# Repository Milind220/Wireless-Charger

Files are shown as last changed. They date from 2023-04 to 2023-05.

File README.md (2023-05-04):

# The *Smart Charge* System

All the code and design files for the wireless charging system that I made for my final year project! This is the capstone project for my undergraduate degree in Energy Science and Engineering!

*Summary*:

A custom built, high power, smart wireless charging system for robotics. The charger transmitter can be controlled from a sleek online dashboard, and the charging mode, output voltage, current, and power can also be monitored. The charger automatically detects the presence of a robot on the charging pad, and switches from STANDBY to ACTIVE charging mode. It also features a closed-loop feedback system to reach the target charging voltage for the robot.



## Contents
* [Inverter-Controller](#inverter-controller) - The code for controlling the inverter.
* [WebLink-Primary](#weblink-primary) - The code for the primary (transmitter) side weblink.
* [WebLink-Secondary](#weblink-secondary) - The code for the secondary (receiver) side weblink. 
* [Secondary-sensor-reader](#secondary-sensor-reader) - The code for the secondary side sensor reader device.
* [Smartcharge-dashboard](#smartcharge-dashboard) - The online control and monitoring dashboard.
* [Hardware](#hardware) - Electronics schematics, gerber files, and STLs.
* [Simulations and Modelling](#simulations-and-modelling) - EasyEDA circuit simulation, and system modelling Excel sheet.
* [Report and Presentation](#report-and-presentation) - my FYP final report and presentation.

## Inverter Controller

The [inverter controller](https://github.com/Milind220/Wireless-Charger/tree/main/Inverter-Controller) is a Teensy 4.1 microcontroller board. It uses 4 precisely timed PWM signals to control an H-Bridge inverter with phase-shift control, which then generates a modified square wave signal that is used to energise the primary (transmitter) coil. It also uses a single digital pin to control the enable/disable function of the MOSFET driver ICs. It also gets signals for the mode to control the inverter from an ESP32 that communicates with it using i2c. 

The Teensy 4.1 was chosen for this task for the following reasons:
* Arduino compatibility, which makes it ideal for rapid development.
* High speed microcontroller. The Teensy's core is a NXP i.MX RT1062 that runs at 600 Mhz.
* Capable of producing very high speed, high resolution, precisely timed and coordinated PWM signals.

The 4 PWM signals are produced as two pairs of complementary signals, with a fixed duty cycle of 50% and frequency of 100 kHz. The two pairs of signals have a variable phase shift (0-90 degrees), and the degree of phase shift controls the output waveform from the inverter. The RT1062's eFlexPWM module also inserts deadtime, so that shoot through doesn't occur between same-side MOSFETs.

A more detailed explaination of the code is given in the Inverter Controller directory. 

## WebLink Primary

The [Primary Side WebLink](https://github.com/Milind220/Wireless-Charger/tree/main/WebLink-Primary) is an ESP32 development board that communicates with the Teensy 4.1 inverter controller via i2c. It obtains the secondary side voltage and current information from the connected Firebase realtime database. This is then used to derive the mode command that it sends to the Teensy. It also sends the Teensy the secondary voltage level, which is used to implement the closed loop control algorithm.

ESP32's are low cost, easy to use, and incredibly powerful (probably overkill for this task). They are also Arduino Compatible, which once again helps with rapid development.

## WebLink Secondary

The [Secondary Side WebLink](https://github.com/Milind220/Wireless-Charger/tree/main/WebLink-Secondary) is an ESP32 development board that sends receiver voltage, current levels to the Firebase realtime database. However, this board does not connect directly to the voltage, current sensors. The sensors used operate at a voltage of 5V, and have analog outputs, which makes it likely that they would damage the ESP32s GPIOs if connected directly. Instead, the ESP32 interfaces with an Arduino Nano via i2c, which is instead used to reads the sensors.

## Secondary Sensor Reader

The [secondary side sensor reader](https://github.com/Milind220/Wireless-Charger/tree/main/secondary-sensor-reader) is an Arduino Nano that reads the analog inputs from the voltage and current sensors. It converts the ADC readings into the actual voltage and current values and then sends those to the WebLink Secondary device via i2c (through a logic level shifter).

## SmartCharge Dashboard

This is the [control and monitoring dashboard](https://github.com/Milind220/Wireless-Charger/tree/main/smartcharge_dashboard) for the SmartCharge System. It is used to view the charging mode, as well as receiver voltage, current, and power in real-time. It can also send on/off commands to the charging station.

## Hardware

This folder contains the electrical schematics and gerber files for the project. This includes the schematics for the inverter and secondary-side control board.

## Simulations and Modelling

This [folder]() contains:
* The EasyEDA simulation done to analyse the resonant frequency of the system, and to confirm the values of the LCC network's capacitances and inductances.
* The MATLAB code used to calculate the LCC compensation network values.
* The Excel file used to model the entire system.

## Report and Presentation

Files in this folder:
1. [FYP final report](https://github.com/Milind220/Wireless-Charger/blob/main/Report%20and%20Presentation/FYP%20Final%20PPT.pptx) 
2. [FYP final presentation](https://github.com/Milind220/Wireless-Charger/blob/main/Report%20and%20Presentation/final_report_55805388_milind_sharma.pdf)

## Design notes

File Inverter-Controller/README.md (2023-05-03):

# Inverter Controller

This is a Teensy 4.1 that is used to control an H Bridge inverter using the PWM outputs. It also communicates with the WebLink Primary board via i2c, and adjusts it's mode of operation according to commands from there.

## General Code explaination

1. Configured as i2c master device.
2. Requests a tranmission from the ESP32 Primary Weblink (slave device)
3. Reads the i2c bytes sent from the slave. 5 bytes are sent:
    1. secondary side voltage (2 bytes)
    2. secondary side current (2 bytes)
    3. mode of operation (1 byte)
4. Switches to the appropriate mode of operation. Different mode functions are defined in the code, and are called from the loop function.
5. The eFlexPWM library is used to control the PWM outputs, and generate two pairs of complementary PWM with deadtime and variable phase shift, at a 100 kHz frequency. These are used to drive the H Bridge inverter.

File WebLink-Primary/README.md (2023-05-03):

# WebLink Primary

This is the Web-link board for the primary (transmitter) side. It receives the secondary side voltage/current from the Firebase realtime database, and sends it via i2c to the inverter controller (Teensy 4.1). The board itself is an ESP32 dev module.

> This is created as an Arduino project, as for some (currently unknown) reason the code refused to compile with Platform.io, but readily compiled with Arduino.

## Brief explaination of code
1. Firebase ESP Client library (v4.3.10) by mobizt is used to get data from Firebase realtime database
2. Wire library is used for i2c communication
3. ESP32 is set-up as i2c slave device
4. It waits for a request from the master device (teensy 4.0 inverter controller), and then sends 5 bytes of data:
    1. 2 bytes for voltage
    2. 2 bytes for current
    3. 1 byte for mode
5. The mode byte is used to indicate the mode of operation of the inverter controller. The modes are:
    1. 0: OFF
    2. 1: STANDBY
    3. 2: ACTIVE
    4. 3: OFFLINE

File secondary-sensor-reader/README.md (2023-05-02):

# Secondary Side Sensor Reader Device

This is the code responsible for reading the values of the voltage and current sensors connected to the receiver (Rx) coil. It is written to run on an Arduino Nnano (AtMega328P).

This is done because the voltage/current sensors used in this project run on 5V while the WebLink (ESP32 board) runs on 3.3V. Thus the sensors cannot be directly connected to the ESP32 without damaging the microcontroller hardware. Since the signal from the sensors is analog, it cannot be routed through a logic level-shifter either. Instead the Arduino Nano reads from the sensors, and sends the readings to the ESP32 using i2c (through a logic level shifter).

## Setup
It carries out the following tasks:
* Reads analog values from voltage and current sensor using ADC.
* Converts ADC values to actual voltage/current readings.
* Sends the values over i2c (through a logic level shifter) to the secondary side WebLink (ESP32 board).

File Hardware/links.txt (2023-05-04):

Inverter: https://oshwlab.com/milind220/new-inverter 
Secondary Side Weblink and sensor reader: https://oshwlab.com/milind220/weblink-secondary

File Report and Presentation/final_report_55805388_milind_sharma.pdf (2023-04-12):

## CITY UNIVERSITY OF HONG KONG

## Development of a Smart Wireless Charging System for Robotics

Submitted to
School of Energy and Environment
in Partial Fulfilment of the Requirements for the Degree of Bachelor of Engineering in Energy Science and Engineering

by

SHARMA Milind

2023.4

s

## Outline

## Acknowledgements:

I am deeply grateful for the support and assistance I have received in the completion of my

undergraduate final project. This project was made possible through a number of grants and

projects, including the grant (Project No. 52077186) from the Natural Science Foundation of

China (NSFC), China; the grant (Project No. JCYJ20210324134005015) from the Science

Technology and Innovation Committee of Shenzhen Municipality, Shenzhen, China; the

grants (Project No.: ITP/027/19AP and ITS-045-21) from Innovation and Technology

Commission (ITC) of Hong Kong SAR; the grant (Project No.: ECF Project 56/2021) from

Energy and Conservation Fund and Woo Wheelock Green Fund of Hong Kong SAR; the

Teaching Development Grant (Project No. TDG 6000784) from City University of Hong

Kong, Hong Kong SAR; the Applied Research Project (9667251) from City University of

Hong Kong, Hong Kong SAR; the grant of Collaborative Research Fund (Project No. C1052-

21GF) from the Research Grants Council of Hong Kong SAR; and the RGC Research Fellow

Scheme (RGC Ref. No. RFS2223-1S05) from Research Grants Council, Hong Kong SAR.

I would also like to express my gratitude to my FYP supervisor, Dr. Chunhua Liu, for his

invaluable guidance, suggestions, and unwavering support throughout the entire duration of

this project. His expertise and advice have greatly contributed to my academic growth and the

development of my research and writing skills. Additionally, I would like to extend my

sincere appreciation to my mentor, PhD candidate Yuxin Liu, who has been instrumental in

shaping my research direction, expanding my professional knowledge, and honing my

practical skills.

Wireless power transfer was initially an unfamiliar area for me, and I encountered numerous

unforeseen challenges while commissioning my prototype. With the continuous support and

encouragement from my mentor, supervisor, and the grants and projects mentioned above, I

was able to overcome these obstacles and successfully complete my project. Their combined

expertise and backing have been indispensable in my journey, and I am extremely thankful

for their mentorship and assistance.

## Abstract:

This paper presents the development of a smart wireless charging system for robotics,

focusing on the integration of IoT technology and an LCC-S compensation-based one-to-one

system operating at 100 kHz. The primary goal of this research is to provide a smart, remote-

controlled, and monitored wireless power transfer (WPT) system that is tailored to charging

robotics systems. By integrating IoT technology, the system allows users to remotely control

and monitor the WPT system via a dashboard, which displays crucial information such as

charging voltage, current, output power, efficiency, and the presence of a secondary coil.

Furthermore, the dashboard facilitates the remote control of the charger's on/off state. In

addition to remote control and monitoring, the IoT system enables feedback control for the

primary side, switching between active and standby modes based on the detection of the

secondary coil. In active mode, the inverter provides constant output to the transmitter coil,

while in standby mode, the output pulses every 500 ms to conserve energy. The IoT system

also dynamically adjusts the phase-shift control in the inverter to regulate output power on

the secondary side, meeting target power requirements. The proposed WPT system

demonstrates a maximum efficiency of 64.28% with a power transfer of 75 W across a 4 cm

air gap, with potential for higher power transfer untested due to equipment limitations. While

designed for the Hunter SE rover, the system can be easily adapted for use with other robotic

platforms. This smart wireless charging system offers significant improvements over existing

solutions, including real-time remote control and monitoring, seamless IoT integration,

adaptability to various robot models, and enhanced charging efficiency.

## Chapter 1: Introduction:

### 1.1. Research Background:

The advent of the electrical age has led to extensive discussions and research on charging and

power transformation technologies. Traditional charging methods that rely on wired

connections, provide considerable power capacity and efficiency but limit mobility, reduce

durability and aesthetics, and impede waterproofing capabilities. Nikola Tesla revolutionized

the concept of wireless power transfer (WPT) with the invention of the Tesla Coil, a high-

frequency, air-core, resonant transformer capable of generating very high voltages and

creating electrical discharges. The Tesla Coil was designed to transmit electrical energy

wirelessly through the Earth's atmosphere, and established the foundation for further research

into WPT technologies [1]. Near-field non-radiative transfer emerged from this area, which

enabled wireless energy transfer across short distances but with relatively low power outputs.

A pioneering study conducted by a team at MIT in 2007, as illustrated in Figure 2, introduced

magnetic resonance power transfer (MRPT), allowing electricity to be transmitted through an

air gap over a few metres with high power capacity [2]–[4]. Innovations like this provided

WPT with the credibility and practicality needed to gain broader adoption and commercial

success, as evidenced by products from WiTricity Corporation [5]. Today, advances in WPT

technology, combined with 'smart' technology, have led to the integration of smart wireless

chargers in most mainstream devices, such as mobile phones, laptops, and headphones. These

chargers typically feature overcharge protection, automatic shut-off when the device is fully

charged, LED indicators for charging status, adjustable charging speeds based on battery

health, and charge optimization, ultimately aiming to deliver efficient charging alongside an

excellent user experience.

(a) (b)
Figure 1: WPT 60W light bulb over 2m distance. (a) Without barrier. (b) With barrier. [2]

The field of robotics, however, has been slow to adopt and implement this technology.

Previous studies on the integration of smart WPT systems with robotics have focused mostly

on coil topologies [6], multiple device charging [7], [8], efficient charging algorithms [9], and

better compensation networks [10]. While these are important areas of research to continue

the improvement of the underlying WPT technology, these papers do not provide a

framework to create charging systems that are easy and modern to control and monitor – both

of which are core tenets of smart technology. Therefore, there is a need for a solution that

integrates true smart features with effective wireless charging abilities and a simple system

architecture.

### 1.2. Research Objectives:

The main objective of this project is to build a wireless charging system for a specific robot

platform, with a novel solution to provide misalignment tolerance, as well as a smart

dashboard and user control interface.

The tasks performed in order to accomplish this goal are listed below:

1. Literature review of the background and history of wireless power transfer, with a

focus on the employment of smart technology in this field.

2. Overview of the design of the WPT system built.
3. Summary of different coil topologies, as well as a detailed analysis on the single

primary, single secondary coil system selected for this project.

4. Design and fabrication of a custom high power inverter circuit board.
5. Analysis of compensation network options, as well as justification and explanation of

the LCC network selected for this project.

6. Integration of a smart online dashboard for control and monitoring of charging system

using Internet of Things (IoT) technology.

## Chapter 2: Literature Review:

Large amounts of research have been done on the field of wireless power transfer and

wireless charging. This section contains a thematically organised summary of the knowledge

required to build an intelligent wireless charging system for a robotics platform.

### 2.1. Development of Wireless Power Transfer:

Conventional charging systems involve connecting a charging plug to a device for power

transfer. This method has several disadvantages: the wire and plug may deteriorate due to

constant plugging and unplugging; the device is confined to a specific location; and sparks

may be produced. Over the years, a wire-free charging technique known as wireless power

transfer has emerged, eliminating the constraints associated with wired charging. This

technology has become increasingly popular and now has numerous applications, including

smartphone and headphone charging [11], implantable medical devices [12], electric vehicle

wireless charging [13], and drone and logistics robot charging [14], [15].

In 1888, Heinrich Hertz discovered the existence of electromagnetic waves and conducted

research into their behaviour. His work helped future scientists understand the concepts of

electromagnetic waves, laying the foundation for future research into this field [16]. Nikola

Tesla, in 1891, made many important contributions to the field of WPT, such as the

aforementioned Tesla coil [1]. However, following this period, due to constraints in

electronic components and related technology, there was limited product development and

research during the early 20th century. Over the following decades, the popularity of

radiation-based WPT gradually increased and in 1966, American engineer William C. Brown

conducted a point-to-point power transfer experiment using radiation, achieving an efficiency

of 26% [17]. Subsequently, in 1968, scientist Peter Glaser theorised about a large solar

powered satellite system capable of converting solar radiation into electromagnetic beams

and transmitting solar energy to Earth [18].These developments eventually led to the

popularisation of non-radiative near-field WPT, which can be further divided into inductive

coupling and magnetic resonant coupling WPT, also known as resonant inductive coupling.

Simple inductive coupling relies on the concept of induced EMF to transfer energy across an

air gap. Magnetic resonant coupling improves on this by additionally also setting both coils to

the same resonant frequency, greatly increasing efficiency and range. The operating

frequencies and transmission ranges of different WPT systems can be seen in figure 2.

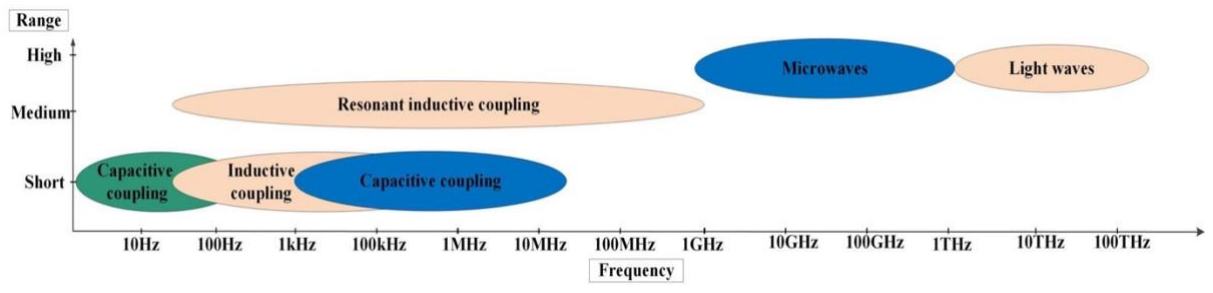
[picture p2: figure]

Figure 2: Review of different technologies in WPT [13].

### 2.2. Fundamental Concepts of Wireless Power Transfer:

Wireless power transfer (WPT) is broadly governed by two fundamental laws of physics,

Ampere's Circuital Law and Faraday's Law of Induction. Ampere's Law states that when a

current flows through a conductor, a magnetic field is generated whose strength is

proportional to the magnitude of the current and the permeability of free space [19]. This

relationship can be mathematically expressed as follows:
∮ B⃗ ∙ dl ⃗ = µ0NI | (1)

Faraday's Law of Induction, on the other hand, states that a time-varying magnetic flux

intersecting a surface formed by a conducting coil induces a time-varying electromotive force

in the circuit, whose magnitude is proportional to the rate of change of the flux and the

number of turns in the coil [20]. This induced emf creates induced current. Mathematically,

this is expressed as follows:

induced emf = −N ∙

dφ
dt | (2)

Together, these laws provide a fundamental model for the interaction between electric

currents, voltages, and magnetic flux in WPT systems. In such systems, two coils, primary

and secondary, are separated by an air gap, and high-frequency alternating current is passed

through the primary coil. This creates a time-varying magnetic field around it, as described

by Ampere's Law. Part of this magnetic flux intersects with the surface formed by the

secondary coil. The amount of flux that interests with the secondary coil is directly related to

the coefficient of coupling, k, with higher coupling implying higher efficiency. In accordance

with Faraday's Law, the magnetic flux induces an emf in the secondary coil, which produces

a current.

However, such systems are inductive but non-resonant and suffer from significant energy

losses through leakage inductance and copper losses in the coils. Coupling efficiency

decreases as the distance between coils increases, making them suitable mostly for close-

range power transfer. For mid-range WPT, an inverter with a large V-A rating would be

required to transmit sufficient power [13]. To fix the flaws of simple inductive coupling,

magnetic resonant coupling is introduced in most practical modern systems. It is well known

that two resonant objects are highly efficient at exchanging energy, while nearby non-

resonant objects are largely ignored. Therefore, the suitability of magnetic resonance for

WPT is even higher since most everyday objects do not interact with magnetic fields [13].

Figure 3: Fundamental concepts of WPT [13].

### 2.3. Integration of Smart Technology with Wireless Power Transfer:

Smart technology, also referred to as the Internet of Things (IoT), consists of a wide array of

interconnected devices leverage advanced sensors, data processing, and communication

capabilities to form a system that can perform tasks intelligently and autonomously [21]. This

technology can be used to develop solutions that enhance efficiency and user experience by

providing a constant stream of information about all devices of any kind in the network [22].

The feature that is key to the effectiveness of smart technology is the ability to process and

analyse real-time data. If applied to a WPT system, this technology could be used to

communicate between the transmitter and receiver coils, provide real-time charging related

information to the user, and even detect issues such as coil misalignment in the charging

process.

In [23], a smart, autonomous WPT system is proposed to enable easy charging for electric

wheelchairs. The paper presents a supervisor system which continuously coordinates and

analyses data between the charging dock and the wheelchair receiver coil, thus maintaining safe operation of the charger at a high level, without requiring human interference. A similar

approach to create a smart wireless charging system for electric wheelchairs is described in

[24], using technology closer to modern IoT to create a hands-free system that communicates

with the central computer of the system via Robot Operating System (ROS) and provides an

Android app that displays charging information and allows the user to control the power

transmitter.

There have also been other approaches to make wireless charging systems more modern,

capable, and intelligent, which can be somewhat classified as smart WPT. One main

approach to improving wireless charger capabilities is through the exploration of multiple-

transmitter/receiver coil configurations. Multiple transmitter coil systems have been used for

the purpose of Dynamic Wireless Power Transfer (DWPT). This variation of WPT

technology aims to enable charging of robots while they operate and are in motion, which is

an improvement over static charging, and could be considered smart charging. One analysis

designed a DWPT system for logistics robots, such as the ones used in warehouses [15]. This

system utilises a many-to-one coil arrangement and an LCC-S compensation network to

enable dynamic charging, and was able to achieve a maximum efficiency of 74.51% at 1.5

kW rated power with the receiver in motion. Other studies have looked into multicoil

transmitter arrays as a method of achieving more intelligent charging. In such systems,

misalignment tolerance is addressed by tracking the position of the receiver coil through

detecting changes in transmitter coil characteristics, and only using aligned coils to transmit

power to the receiver [6].

‘Smart’ multiple receiver coil systems (one-to-many) have also been explored. One such

system, designed with a single transmitter and 3 miniature receiver coils, developed a method

based on separating the resonant frequencies of the receivers to select and deliver power to

only one receiver coil at a time, eliminating cross coupling losses [25]. Using this approach, a

maximum efficiency of 29% was observed despite the small coupling coefficient of only

0.01. These advanced coil arrangements each have specialised advantages. One-to-many

chargers allow for charging of multiple devices; many-to-one arrangements provide much

greater misalignment tolerance; many-to-many arrangements incorporate advantages of both.

While these different coil arrangements are often necessary to solve certain problems, they do

not make use of the advancements of the IoT sector. Thus, they forego the benefits of online

monitoring, remote control, and more advanced communication channels.

Another area of advancement for wireless charging has been in the development of charging

standards, such as the “Qi Standard” developed by the Wireless Power Consortium and

“Power Matters Alliance Standard” (PMA) developed by the Airfuel Alliance. Among other

things, these standards specify the design of a communication standard between the

transmitter and receiver [11]. This is related to smart technology as it provides the simplicity

to use any standard-compliant transmitter-receiver pair and have the wireless charging work

correctly. It is important to note that transmitter-receiver communication occurs over the

same coils used for charging, adding a degree of complexity to the charger design [26]. The

PMA standard does incorporate smart features, emphasizing cloud-based device

management, offering smart features such as usage monitoring, remote diagnostics, and over-

the-air firmware updates [11].

(a) (b)
Figure 4: Smart interface for WPT system [24]. (a) Relationship between system central computer and android app. (b) Android mobile application used for monitoring and control.

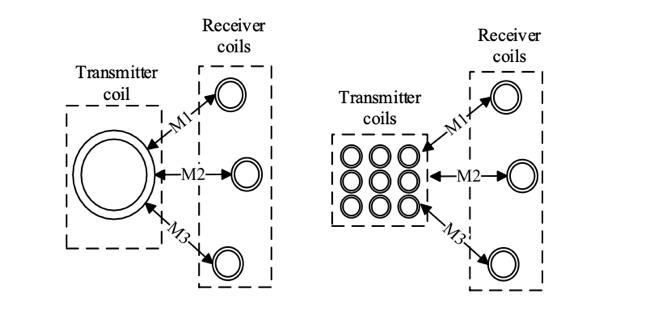
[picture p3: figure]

(a) (b)
Figure 5: Multiple receiver coil topologies; (a) Single In Multiple Out (SIMO) and (b) Multiple In Multiple Out (MIMO).

### 2.4. Motivation and Description of the Project:

The motivation for pursuing this project comes from my experience in robotics and software

development. During a summer internship at a robotics company, I noticed that in most cases,

the robots had to be manually charged using a wired connection – a repetitive task that should

have been rendered outdated with the popularisation of wireless charging and smart technology. Further research revealed that most robotics systems that are WPT enabled are

either very high power applications (kW), very low power application of a few Watts or less

[27]. As such there is a dearth of ready-made medium power WPT capabilities for robotics

platforms.

The purpose of this project is to introduce a truly smart wireless power transfer system that is

custom built for a specific robotics system, to provide exact charging voltage and current that

it requires. Affordable and modern IoT technology connected to the WPT system will enable

the creation of a multi-platform, online charger control and monitoring dashboard.

Information gathered by the IoT devices on the receiver and transmitter sides will also be

analysed in order to implement a feedback and control system. Using this, the transmitter coil

will be switched to standby mode if receiver coil is not detected to save energy. Also the

inverter output power will be varied using phase-shift control, based on the feedback obtained

from the secondary coil. The system will use an internet enabled microcontroller board on

both the transmitter and receiver sides in conjunction with other system elements to facilitate

the IoT features. The proposed system will feature a one-to-one (O2O) coil arrangement

where both coils are identical in size and shape to simplify the coil architecture. An

appropriate LCC compensation network will utilised in order to reduce sensitivity to

variations in coupling coefficient and load impedance, which leads to higher stability and

efficiency. The online dashboard will be used to control the charger system and view

charging information in real-time remotely. This, along with a modern and appealing design

for 3D printed enclosures will result in a WPT system that is both a capable charger and also

user friendly and visually appealing.

## Chapter 3: Methodology:

The section on methodology consists of two sections. The first section, theoretical

framework, contains all the theoretical concepts and design principles involved in this

project. The second section, experimental methodology, covers the steps taken for the

practical design of the system, how certain parameters were experimentally determined, and

how certain components were selected. This includes measurements, simulations, and other

practical design decisions.

### 3.1. Theoretical Framework:

### 3.1.1. General System Architecture:

Figure 7 displays the architecture of the smart WPT system proposed in this paper. In this

section, a general system overview is provided with a focus on the WPT parts, while section

3.1.6 covers the IoT network structure in detail.

On the primary side, stable DC power is supplied to the inverter, which then modulates it into

a modified square wave. The transmitter (Tx) coil is energised by the modified square wave

and compensated by the LCC network so it resonates at the system operational frequency. In

this state, the Tx coil transfers energy to the receiver (Rx) coil across an air gap. On the

secondary side, the induced voltage produces alternating current, which is then compensated

and rectified into direct current. The direct is then used to charge the load. The proposed coil

design consists of inverter, LCC-S compensation network, and one-to-one transmitter and

receiver coil system. The primary and secondary side are both additionally monitored by

internet enabled microcontrollers, which process and send charging information to an online

database. This information is then available for viewing on the online dashboard, and also

used to implement feedback control for the primary side without manual operation.

### 3.1.2. Coil Topology:

In this paper, a one-to-one coil (O2O) topology – as shown in figure 8 [28] is proposed,

utilizing identical circular coils for both the primary (transmitter) and secondary (receiver)

sides. This configuration provides a simple approach to wirelessly transfer power between the

charging station and the robot, which reduces system complexity.

A O2O topology is a suitable choice for applications where a single transmitter coil (TX) is

supposed to charge a single receiver coil (RX) on the robot. This configuration offers the

advantage of straightforward design, as it does not require the complex control mechanisms

and communication protocols needed for multi-coil arrangements. O2O coil topologies also

simplify the problem of stable and efficient power transfer in the event of misalignments

between the charging station and the robot, as fewer coil positions have to be taken into

account. Lastly, the simple design of the O2O topology allows this paper to focus on the

implementation of a robust smart IoT network.

Figure 7: One-to-one coil topology [28].

Figure 6: System architecture of proposed smart WPT system

### 3.1.3. Coil Modelling:

Prior to design of the physical coils, coil modelling was performed to obtain estimations of

their properties in advance. As described in detail in section 3.2.2., circular coils were chosen

for this system. These parameters were modelled for circular coils: self-inductance; inner

diameter; coil area. All modelling in this section is based on the framework laid out in [29] as

applied in [30], and can calculate inductance with ~1% maximum error:
Din(mm) = Dout − (2N ∙ (dwire + s)) | (3)

Where Din is inner diameter of coil, Dout is outer diameter of coil, N is number of turns,

dwire is wire diameter, s is turn spacing (all distances are in mm). Wire length can be

calculated from this as well, which can help derive coil resistance.

wire lengtℎ (m) =

Nπ
1000 ∙

(Din + Dout)
2

(4)

Inductance can also be estimated in this manner. R and W are intermediate parameters used

for this calculation, and their derivations are in the Appendix.

inductance (µH) =

R

2
- N

2
8R + 11W

(5)

### 3.1.4. LCC-S Compensation Network:

For the system proposed in this paper, a LCC-S (inductor-capacitor-capacitor-series)

compensation network is utilised. The decision to utilise an LCC network is based on the

principle that it can facilitate constant output voltage and constant primary coil current. The

working principles behind this compensation technique are discussed in this section.

The requirement for a compensation network in WPT systems stems from desire to

improving certain characteristics in the system. For the system proposed in this paper, those

characteristics include: constant current/constant voltage output that is not sensitive to load

resistance; Low input reactive power, Low sensitivity to variation in the coupling coefficient,

which can broaden the range of possible applications [31]. Of the many initial compensation

networks that emerged as options, series-series (SS) compensation was the most effective to

achieve these goals [32]. However, due to low performance in the event of coil misalignment,

higher order compensation such as LCC networks have been explored [33], [34]. Figure 8 shows the practical configuration of the LCC-S compensation network, where LP1

, CP1 and

CP2 are the inductance, parallel capacitance, and series capacitance in the compensation

network, and LP is the inductance of the primary coil. As mentioned earlier, a feature of LCC

compensation networks is that when operating at the resonant frequency, transmitter coil

current is independent of the coupling coefficient and secondary coil load, facilitating

constant current output for the transmitter. In order for this to happen, the following

relationships must be satisfied [33]:

jωLP1 = −

1
jωCP1

→ LP1

- CP1 =

1
ω²

(6)

jωLP1 = jωLP +

1
jωCP2

→ (LP1
- LP

) ∙ CP2 =

1
ω²

(7)

To further analyse the LCC compensation, Figure 9 shows the T-equivalent circuit diagram

of the resulting system when the transmitter and receiver coils are coupled together, which is

used for showing the constant primary current. The impedance reflected from the secondary

side is represented here as Zre1
. Using this, the total impedance on the primary side can be

calculated:

Z0 = jωLP1 +

1
jωCP1

|| (

1
jωCP2
+ jωLP + Zre1) | (8)

Simplifying (8) using equation (6) and (7), we derive a new equation for Z0 :

Z0 =

ω²
- LP1

2

Zre1

(9)

This can now be used to model the current in the transmitter coil, assuming that the voltage

provided in the transmitter coil by the inverter is Uin1
. Equation (5) can be then be derived:

IP1 =

Uin1

∙

1
jωCP1

|| (

1
jωCP2

+ jωLP + Zre1)

Z0

- (

1
jωCP2

+ jωLP + Zre1)

(10)

Which can then be simplified further to:

IP1 =

Uin1
jωLP1

(11)

Equation (11) shows that the value of IP1
, the transmitter coil current, is not dependant on the

impedance reflected from the secondary side. This ensures that any variation in mutual

inductance that occurs when the robot is moving on the charging station does not affect the

current in the primary coil.

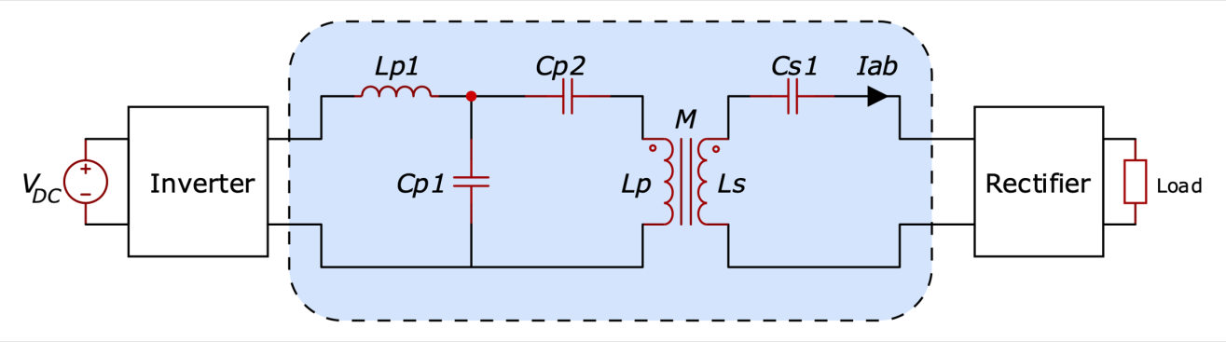
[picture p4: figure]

Figure 8: Practical configuration of LCC-S Compensation Network.

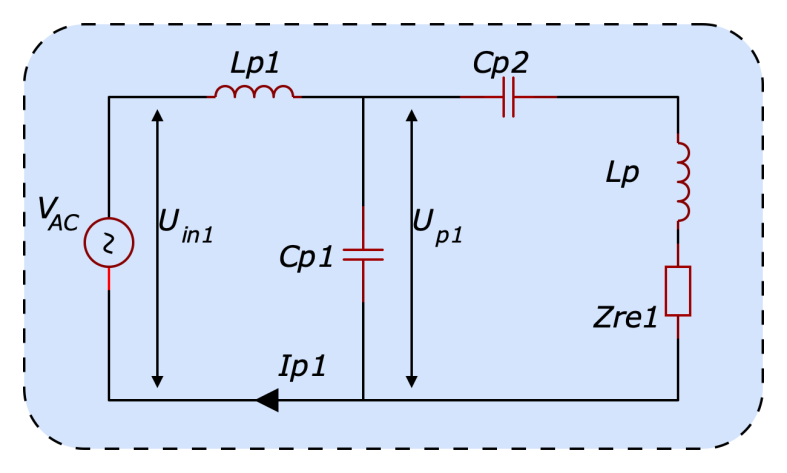
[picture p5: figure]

Figure 9: T-Equivalent circuit of primary side to show constant Tx coil current.

### 3.1.5. Inverter Control Algorithm:

For this system, phase-shifted pulse width modulation (PWM) with dead-time insertion is

used to control the inverter [35]. An H-Bridge circuit can be driven by 4 PWM signals to

control the voltage waveform on the primary of a transformer, or in the case of this paper, a

WPT system. The PWM signals are generated as two pairs of complementary signals, with

one pair phase shifted by an angle of θ in comparison with the other. As a result, the primary

coil receives the bottom waveform – known as a modified square wave - across its terminals.

The RMS voltage of this waveform is directly controlled by the degree of phase shift between

the two sets of square waves. A phase shift of θ = 0° results in minimum voltage output,

while a phase shift of θ = 180° results in maximum voltage output. Independent of the phase shift, no DC component appears in the load voltage provided the square wave duty cycle

remains at 50%. This is well suited for inductive loads, and as a result, this is frequently used

in WPT system inverters to deliver an adjustable amount of power to the Tx coil [36]. Figure

10 shows the four PWM signals, as well as the 90° phase shift that will be used as standard

operation, although the amount of phase shift will be dynamically adjusted during the

operation of the system. Dead-time is also added in between complementary signal edges.

This is a short period where both MOSFETs in the same leg of the H-bridge are signalled to

switch off, to prevent a short circuit, or ‘shoot-through’ from occurring.

This phase-shift output can be easily implemented in a 32 bit microcontroller board, such as

the i.MX RT1060, reducing cost and complexity. The choice of microcontroller board is

discussed in detail in 3.2.9.

Figure 10: H-bridge configuration with phase shifted PWM control signals, with modified square wave output [38].

### 3.1.6. IoT Network Structure:

A smart IoT network, as shown in figure 11, is integrated with the WPT system in this paper.

This network consists of four main blocks: The secondary side feedback detector; Primary

side feedback controller; Online database; and Control and monitoring dashboard. An

explanation of how all system blocks interact with each other is provided below.

Moving from the right to the left, the secondary side feedback detector block is responsible

for detecting the DC voltage and current being supplied to the load by the rectifier. It uploads

this data to the database in real-time, from where it can be viewed on the online dashboard.

The information is also constantly synchronised to the primary side feedback controller,

which then tells the inverter whether to increase or decrease the voltage in the Tx coil.

Additionally, the AC voltage and current in the Tx coil is also measured by sensors, and

synchronised to the database in real-time. This allows for live measurement of power transfer

efficiency, η =

VS ∙

IS

VP∙

IP

, which can also be displayed on the dashboard for the user to view.

Lastly, the entire system can be switched between modes such as on/off/standby remotely

from the control dashboard. An explanation of the effect of these modes is provided in 3.1.7.

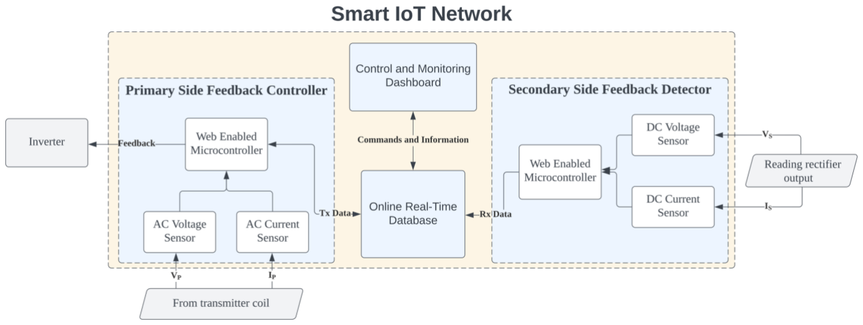
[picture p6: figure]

Figure 11: Smart IoT network for WPT system.

### 3.1.7. Smart Feedback Control Algorithm:

Figure 12 shows the closed-loop algorithm that controls the flow of the sensing of Rx side

voltage and current, and the signal sent to the inverter. Voltage and current induced in the Rx

coil will rise as the coil approaches the Tx coil, and in this way the presence of the Rx coil

can be detected, and feedback control for the inverter can also be implemented.

The modes work in the following manner: The inverter can be OFF, STANDBY, and

ACTIVE modes. When the inverter receives a disable command, it’s in OFF mode, where

there is no output. If the inverter receives an enable command but the Rx coil is not detected,

the inverter is placed in STANDBY mode, where it pulses voltage in the Tx coil only periodically. As the secondary side voltage is continuously sampled, this is used to check the

presence of the Rx coil on the charging pad – If this voltage crosses a threshold, the Rx coil is

considered detected and present on the charging station. The inverter then is placed in

ACTIVE mode, where it continuously generates the output waveform to power the Tx coil.

This is shown clearly in table 1.

The feedback control works in the following way. When the inverter is in ACTIVE mode, but

the secondary voltage is still insufficient to charge the robot battery, then the inverter is

signalled to increase the degree of phase shift to increase the voltage. It should be noted that

there is a limit to the voltage that the inverter can produce in this manner, but it would still

increase the overall tolerance to misalignment greatly.

Table 1: State table for mode control.

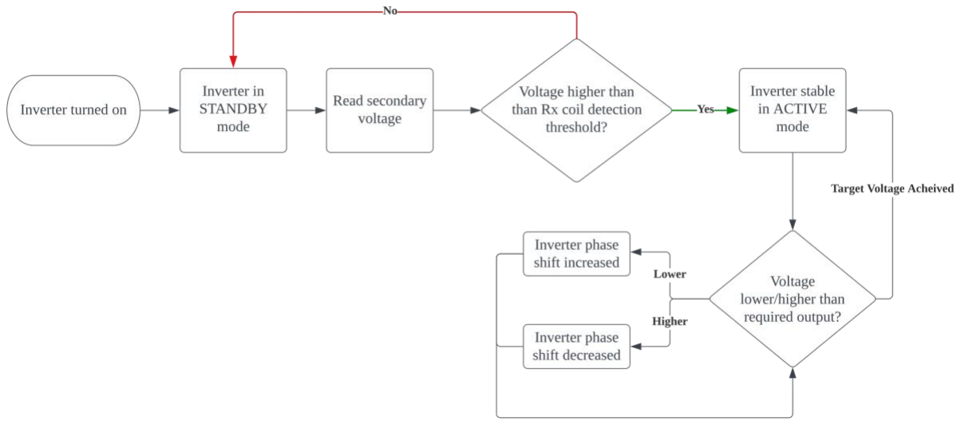
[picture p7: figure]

Figure 12: Closed loop algorithm to implement smart feedback.

### 3.2. Experimental and Practical Setup:

### 3.2.1. Selection of Robot Platform:

For the practical implementation of the smart WPT system described in this paper, a robotics

platform had to be selected. I was given the choice between two robots that were available in

the laboratory at the time. Figure 14 (a) shows the first option - Xiaomi’s CyberDog Bionic

Enable command received? | Rx coil detected? | Mode
No | N/A | OFF
Yes | No | STANDBY
Yes | Yes | ACTIVE

Quadruped robot, while figure 14 (b) shows the second option – the Hunter SE rover by

AgileX.

The Hunter SE Rover was chosen as the robotics platform for this project for two reasons:

1. Level Underside: For this WPT system, the Rx coil has to be mounted on the

underside of the robot chassis. In the case of the quadruped robot, the relative angle of

the chassis changes with respect to the ground, where the charging station would be

placed. This would add complexity and require greater amounts of misalignment

tolerance that go beyond the scope of this project. As such as the flat, constantly level

chassis of the rover provides the perfect mounting point for the Rx coil and secondary

circuit components.

2. Lower Dynamic Stress: The Rx coil, rectifier, and secondary side IoT components

would all be mounted to the robot. For quadruped robots, due to their jerky

movements while walking, there would be higher dynamic stress on these

components. Once again, this would add complexity to a project where the focus is

the development of a smart WPT system. Instead the smooth movement of the rover

provided a better development platform for this purpose.

(a) (b)

Figure 13: Robotics platform options. (a) CyberDog Bionic Quadruped Robot [37]. (b) Hunter SE Rover [38].

### 3.2.2. Charger Output Requirements:

The Hunter SE Rover has the following charging requirements [39]:

Charging voltage: 24V DC (constant voltage)

Charging current: 15A maximum current.

### 3.2.3. Coil Design:

Designing optimal Rx and Tx coils is essential for any WPT system. For this project, I started

the process of coil design by looking at the initial constraints. Since the Rx coil must be

mounted on the underside of the Hunter SE rover chassis, one important constraint is the size

and shape of this coil. I aimed to use the largest coil size possible for the Rx/Tx coils, as this

allows for greatest power transfer. Figure 15 shows the dimensions of the robot, from which

it is clearly visible that the width of the robot, equal to 230 mm, would be the limiting factor

[38]. I also physically verified this measurement.

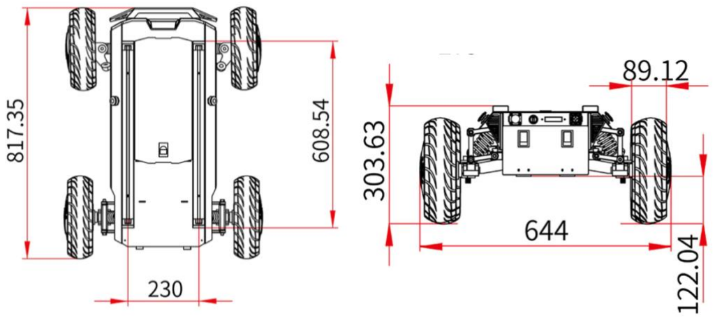
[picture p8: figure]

(a) (b)

Figure 14: Dimensions of the Hunter SE rover (a) Top view. (b) Front view [38].

I chose to use circular coil (planar spiral) for the Tx/Rx coils, due to the following reasons:

1. Symmetric magnetic field distribution, providing intrinsic misalignment tolerance and

lower sensitivity to coupling factor variation.

2. High coupling coefficient, due to their symmetric shape.
3. Scalability. The diameter of circular coils can be changed to make them bigger or

smaller without significantly affecting system performance.

4. Straightforward fabrication, as they are easy to wind.
5. Readily available commercially. This would lower costs and production time if

widespread adoption of this proposed WPT system occurs.

As explained in 3.1.3, coil modelling was carried out prior to physical winding of the coil in

order to understand what an optimal number of windings would be. Various numbers of turns

were simulated, with the wire being 0.1 x 350 Litz wire. The modelled characteristics are

shown in Figure 15. Coils with 15 turns were selected due to their relatively high self-inductance, while maintaining lower resistance. This is in contrast to the model, which might

suggest that higher number of turns is better. In practice, the larger number of windings

would result in a lower coil quality, and lower the power transfer.

Figure 15: Coil modelling showing resistance and inductance for coils of outer diameter 230mm for varying number of turns.

I elected to use identical Tx and Rx coils for the highest coupling and power transfer

efficiency. The Rx/Tx coils that were made are shown in figure 16, and the 230 mm outer

diameter is shown in figure 17. As mentioned earlier, 0.1 x 350 Litz wire (350 strands of

0.1mm diameter each) was used. This is done to mitigate the ‘skin effect’, which is the

increase of effective resistance to current at high frequencies [40]. It is caused by the current

not penetrating fully into the conductor, and instead flowing more on the skin of the

conductor.

1 | 3 | 5 | 7 | 9 11 13 15 17 19 21 23 25 27 29 31 33 35 37

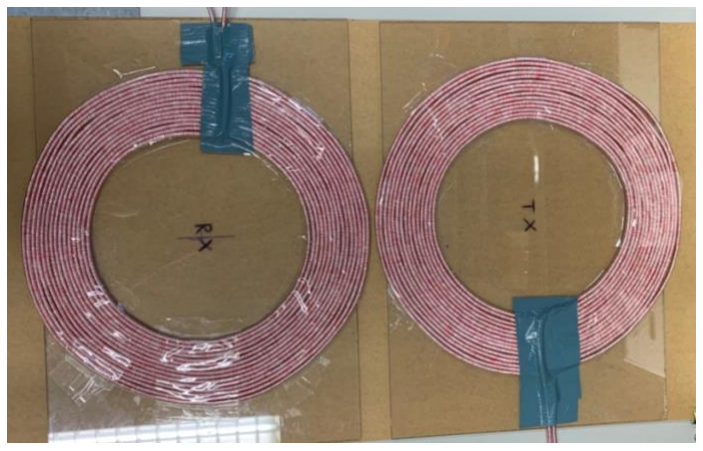
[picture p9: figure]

Figure 16: Identical Tx and Rx coils with 15 turns wound with Litz wire on acrylic glass.

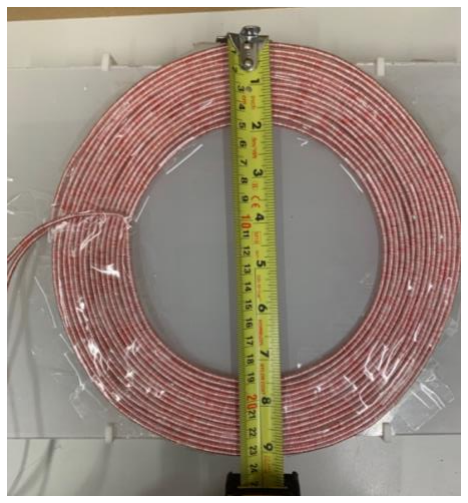
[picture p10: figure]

Figure 17: Verification of 230 mm outer coil diameter.

### 3.2.4. Determination of Operational Frequency:

For a WPT system, the selection of the operational frequency is an important design decision

that influences the system's performance and efficiency. However, since the operational

frequency is interrelated with other aspects of the system, as shown in equation 12, it cannot

be simply calculated, as there are more unknown variables than equations. Instead, it must be

either determined experimentally, fixed arbitrarily, or calculated using another component

value which has been arbitrarily fixed.

fres =

1
2π√LC
, wℎere fres and C are botℎ unknown | (12)

For the limited scope of this paper, I selected 100kHz as the operational frequency. This is

justified as following:

1. Switching losses: Very high frequencies (several 100 kHz) can lead to increased

switching losses in power electronic devices such as MOSFETs. At 100 kHz, a good

balance between lower switching losses and efficiency may be achieved.

2. Compatible with existing systems: Many existing WPT systems reported in literature

currently operate between 50 kHz and 300 kHz. This system can then be compared to

them easily.

3. Lower skin effect: At 100 kHz the skin effect can be effectively mitigated by using

Litz Wire, as the current will mostly penetrate throughout the 0.1 mm strands.

4. Convenience: Fixing the operational frequency allowed me to design the rest of the

system effectively.

### 3.2.5. Measurement of Inductances:

I used two LCR meters: the Keysight E4980AL (Figure 18) and the Victor 4080 handheld

meter (Figure 19) to measure the self-inductances and mutual inductance (M) for the coils

respectively, using identical settings of 100kHz and 1V on each.

The method for deriving mutual inductance is from [41]. Initially, the device's input

impedance is checked and series inductance LX is measured with the primary and secondary

coils connected as shown in Figure 20 (a). Next, this measurement is repeated again with the

opposite series connection between the coils, as shown in in Figure 20 (b), giving us LY. The

mutual inductance M is then calculated using:

M =

LX − LY
4

(11)

Figure 18: Keysight Technologies E4980AL Bench LCR Meter.

Figure 19: Victor 4080 handheld meter.

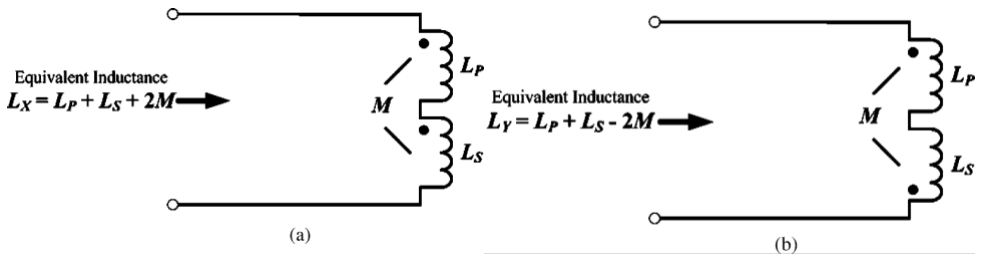
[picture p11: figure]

Figure 20: Different connections for mutual inductance measurement [41].

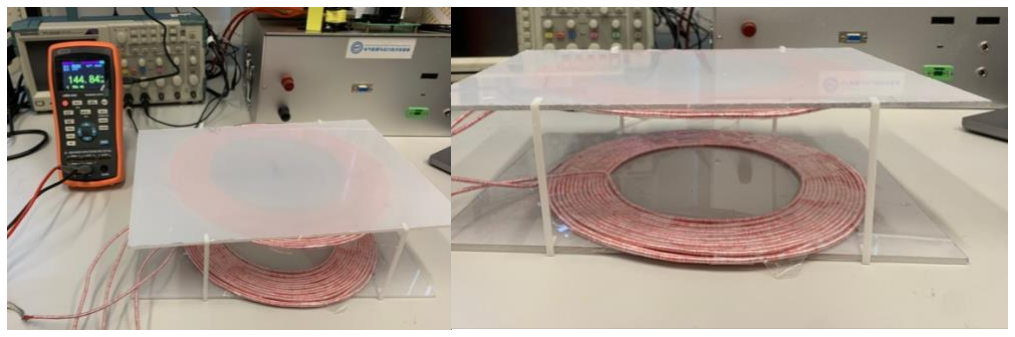
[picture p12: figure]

Figure 21: (a) Mutual inductance measurement, and (b) custom clips used for this.

The mutual inductance measurements were done across a varying set of heights. I designed

and 3D printed sets of clips, seen in figure 21, that separated the Tx and Rx coils by a set

distance. I tested distances between 0 cm and 10 cm as the Hunter SE rover has a ground

clearance of 12.2 cm, seen in figure 14 (b), and certain margin has to be left for the

electronics installation. Also, the calculation of coupling coefficient has been done here as

well:
k = M√Ls ∙ Lp | (13)

Since the measurements are prone to error caused by interference from proximity to

conductive materials, and the laboratory workbench is littered with these, the following steps

were taken to mitigate errors:

1) For self-inductance measurements, each coil was lifted high above the workbench

during measurement, to reduce the proximity to conductive materials.

2) The handheld meter was used on a separate desk for mutual inductance measurements

as there was insufficient place on the workbench for the Rx/Tx coils to be placed

without major interference with the readings.

3) Custom 3D printed clips were used to stabilise the coils and reduce error due to

movement during mutual inductance measurement (Figure 21).

4) The average of two readings was taken for each measurement to reduce error.

The results for these measurements are shown in Table 1, Table 2, and figure 22.

Table 2: Self Inductance Measurements for Primary and Secondary Coil.

Primary Coil Lp | Secondary Coil Ls | Unit
Series Inductance Ls | 60.88 | 61.17 | µH
Series Resistance Rs | 84.30 | 85.00 | mΩ

Table 3: Mutual Inductance Measurements for Coil System.

Spacer height (cm) | Lx (µH) | Ly (µH) | M (µH) | Coupling factor k
0 | 224.08 | 14.78 | 52.325 | 0.8574
2 | 193.35 | 40.46 | 38.223 | 0.6263
4 | 168.55 | 66.69 | 25.465 | 0.4173
6 | 154.16 | 84.21 | 17.488 | 0.2866
8 | 144.65 | 94.30 | 12.588 | 0.2063
10 | 137.83 | 101.06 | 9.193 | 0.1506

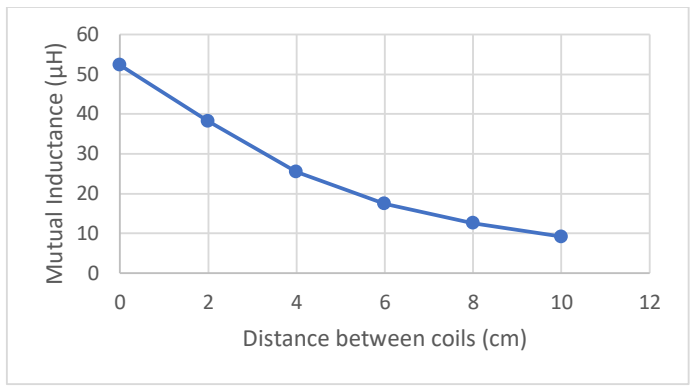
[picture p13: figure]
Mutual Inductance (µH); Distance between coils (cm)

Figure 22: Mutual inductance vs coil separation.

### 3.2.6. Selection of System Coil Separation:

For the proposed WPT system designed for the Hunter SE rover, the maximum ground

clearance of the robot is 12.2 cm. Also the mutual inductance has been tested for values

between 0 cm and 10 cm. This concludes all the information needed for the selection of the

separation distance for this system. A larger separation distance would have more margin for

error and would be safer, as there would be lower chances of collision between the robot and

the charging station. However, this would also result in lower coupling between the Rx and

Tx coils, and thus lower efficiency of transfer. A lower separation would have higher

coupling, but also greater chances of collision.

Thus, a moderately short separation distance of 4 cm is selected, which would allow high

coupling with a low enough risk of collision.

### 3.2.7. Simulation and Determining of LCC-S Compensation Values:

I used MATLAB programs to calculate the inductor and capacitor values used in the LCC-S

compensation network. The equations used are from derived from the basic equations for

resonant circuits, as well as from [33]. For these calculations, the operational frequency of

100 kHz is entered. Also, to enable easy calculation, I fixed the value of the primary side

series inductor to be 5 µH. This is also entered into the equations as a constant value. The

MATLAB code used for the calculation is shown in figure 23. The results of the calculation

are shown in figure 24.

The resulting values for resonance condition at 100 kHz are:

LP1 = 5 µH; CP1 = 506.61 nF; CP2 = 45.33 nF; CS1 = 41.41 nF

(a) (b)

Figure 23: MATLAB calculations of LCC-S components. (a) Primary side. (b) Secondary side.

Figure 24: Calculated values of compensation network capacitors and inductor.

A spice simulation was also done to double check that the values have been calculated

correctly. The simulation was set up to conduct an AC Analysis, and pass AC frequencies

between 10k and 200k through the coils and compensation network. The output waveform

was set to detect the voltage induced in the secondary coil, which should be highest at the

resonant frequency of 100kHz if the system parameters are set correctly. Figure 25 shows the

schematic for the simulation, figure 26 shows the result, which proves that the values were

correctly calculated.

Figure 25: AC frequency analysis simulation in EasyEDA (uses the Ngspice engine).

Figure 26: Simulation result, voltage in secondary coil highest at 100kHz frequency.

### 3.2.8. Custom Inductors and Capacitors:

Obtaining exact values for the capacitances and inductance involved in the LCC-S network is

important for optimal performance of the WPT system. As seen in 3.2.6., the values are

extremely specific, and thus cannot be readily purchased. For the capacitance values, several

capacitors must combined in series and parallel to get the exact value. Non-polarized

capacitors are used as the compensation network has to handle AC. Since the capacitors have

error tolerances of ~1-5%, the values of each one had to be measured using the Victor 4080

handheld LCR meter prior to use (figure 27). After selecting all the smaller capacitors, I

soldered them in parallel on proto-boards to obtain one large capacitor, as seen in figure 28.

This was done for CP1

, CP2

, and CS1

For the inductor, while 5µH is not a difficult value to obtain readymade, it is better to hand-

wind it. This allows the wire material and the inductance to be precisely controlled. Some

benefits are:

1. Litz wire can be used: As explained in 3.2.3, the multi-stranded nature of Litz wire

mitigates the skin effect. Since this inductor will compensate the WPT system at 100

kHz, this is necessary to increase the efficiency and keep effective resistance low.

2. Precise control: The inductor was hand-wound around an air core, which allowed for

minute changes in the inductance to be realised. Around 6 turns were required to get

close to 5µH. I then trimmed off small sections of wire and remeasured the inductance

until an almost exact value of 5µH was achieved.

Figure 27: Capacitance measurement using handheld LCR meter.

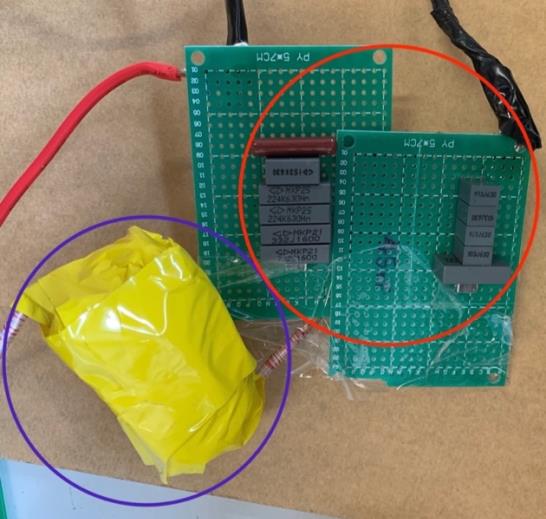
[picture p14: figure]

Figure 28: Hand-wound inductor Ls covered in Kapton tape (blue circle), Several parallel capacitors connected to form Cp1, Cp2. (red circle). The image shows all three components connected in LCC configuration.

### 3.2.9. Selection of Microcontroller Board:

The main consideration behind selection of these boards was 1) Speed and Processing Power:

32-bit microcontrollers, high clock speed, enough RAM and Flash memory, and 2) Ease of

Development: I wanted to use Arduino compatible microcontrollers to leverage the large

number of libraries available for the code.

For the control of the inverter, two microcontroller development boards were considered –

PJRC’s Teensy 4.1 and Texas Instruments LaunchXL-F28379D, both of which have 32-bit

microcontroller units (MCUs). However, I chose the Teensy 4.1 board due to higher speed, smaller form factor, ease of development, lower cost, and only needing a single core. Table 4

shows a comparison of the two board’s features, and figure 24 shows the two boards side by

side. For the IoT connectivity, ESP32 microcontroller boards, shown in figure 25, were

selected. These are 32-bit MCUs with 2.4 GHz Wi-Fi and BT/Bluetooth LE support

{Citation}. They are inexpensive, powerful, and are Arduino compatible. All the MCU

boards are shown in figure 29.

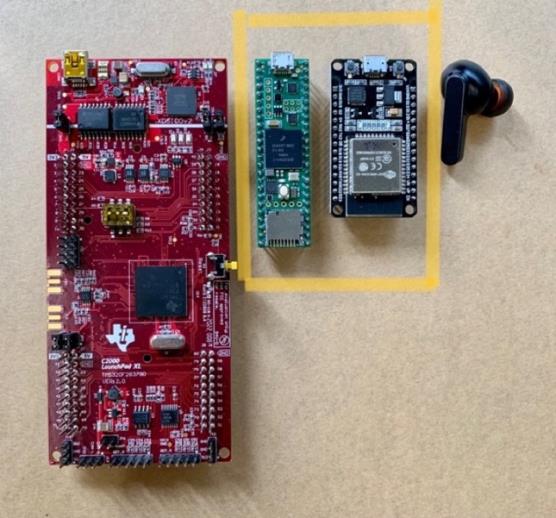
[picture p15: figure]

Figure 29: LaunchXL F28379D (far left), Teensy 4.1 (middle left), ESP32 (middle right), earbud for scale (far right). The highlighted boards are the ones being used.

Table 4: Comparison of Teensy 4.1 and LaunchXL 28379D [42], [43].

| Teensy 4.1 | LaunchXL 28379D
Processor speed | 600 MHz | 200 MHz
Price | ~ 32 USD | ~ 58 USD
Memory | 8Mbyte Flash, 1024KB RAM | 512KB flash, 204KB RAM per core
Float math support | Yes | Yes
Cores | 1 | 2
Arduino compatible | Yes | No

## Chapter 4: Results

### 4.1. Inverter Design:

To energise the Tx coil, two versions of the inverter were conceived. First, I designed a lower

power inverter (inverter A) to increase my familiarity with electronics design tools, and then

created the high power inverter (inverter B) that is finally used. Inverter A uses simpler

components that had extensive design guides available. The schematic for inverter A is

shown in figure 30. It uses bootstrapped high-side MOSFETs to provide them with sufficient

gate-drain voltage for switching. An advantage of this inverter is that it would allow the

frequency to be easily adjusted using a trim potentiometer connected to a NE555 timer IC.

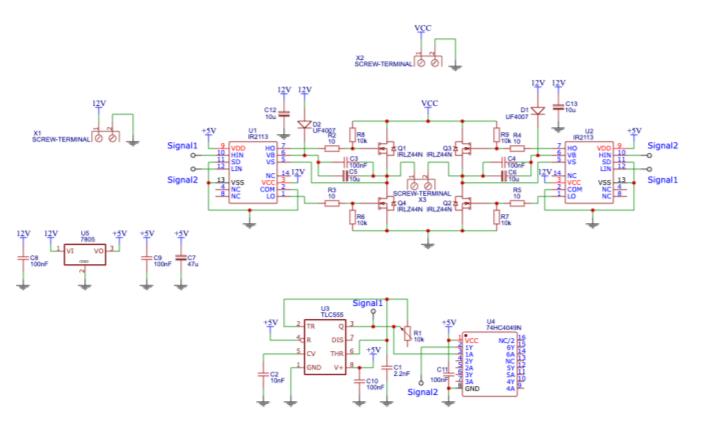
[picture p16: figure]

Figure 30: Lower power inverter A schematic.

However due to Inverter A’s limitations in output power, maximum frequency, and control, I

designed Inverter B (schematic in figure 31). This is a high power, single phase, full H-bridge

inverter, capable of output of several hundred Watts. It also arranges the MOSFETs in a

bootstrap configuration. The two key components used are Woolfspeed C3M0060065K SiC

power MOSFETs, and Infineon 2EDF9275F gate driver ICs. These are meant for high power

and high speed switching. The fabricated, assembled inverter PCB is shown in figure 32.

An explanation of the working of this board is provided here: 4 Pulse-width modulation

(PWM) signals are used to control the four MOSFETs on the inverter. These are supplied to

four pin connector (H1). Three additional pins (H2) on the inverter PCB are used for

connection of voltage, ground, and enable/disable signal for the gate driver ICs. The screw

terminals on the board do the following: X1 is used to supply the high voltage (VCC) for the

output; X2 is used to supply the bootstrap gate drive voltage of 15V; X3 supplies the output waveform, and is where the Tx coil would be connected. Many passive components

(resistors, capacitors, diodes) are connected to enable this circuitry. An aluminium heatsink

was also added to the MOSFETs on the inverter to enable prolonged high power use.

Figure 31: Schematic of High Power Inverter (Inverter B).

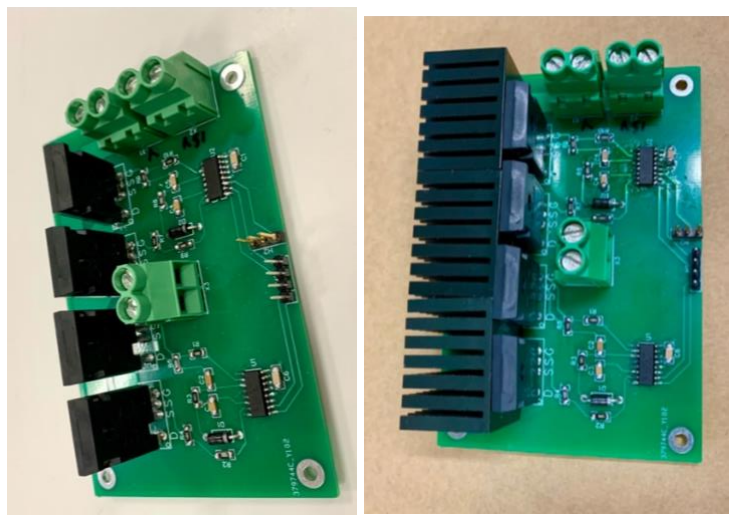
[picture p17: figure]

Figure 32: Inverter B, before and after the addition of a heat sink

### 4.2. Inverter Control:

The primary side overall control board consists of the Teensy 4.1 and one ESP32

communicating with each other via the i2c protocol.

Figure 33 shows a section of the C++ code used in the Teensy 4.1 to control the inverter. The

code for the inverter control makes use of the eFlexPWM module of the MX RT1062 MCU,

as well as a library that facilitates easy and comprehensive use of all the PWM features that

the board has to offer [44]. The PWM frequency is set to 100 kHz, and the duty cycle is fixed

at 50%. The code activates ‘complementary mode’ for the PWM generation, which allows the generation of two sets of complementary signals. Deadtime is also set, allowing each

MOSFET enough time to close before the other one in the same half-bridge opens, to prevent

current shoot-through . The phase shift is dynamically configurable, and the information for

the degree of phase shift is received from the i2c connection to the ESP32. There is also a

state machine set up with three modes. The Teensy receives information about the mode from

the ESP32 via i2c. OFF mode disables the gate driver output, turning the inverter off.

STANDBY mode enables the gate drive, increases phase shift to reduce output power, and

pulses the Tx coil every 500ms. This is used to detect the presence of the Rx coil. ACTIVE

mode generates the output PWM continuously for full inverter output, and allows for

dynamic adjustment of phase shift. Figure 34 shows the inverter output in ACTIVE mode,

with 90 degrees or 50% phase shift, which is standard operation. Figure 35 shows the inverter

output during a pulse in STANDBY mode. The Tektronix TPS 2024B oscilloscope was used

for visualisation of waveform results (figure 35).

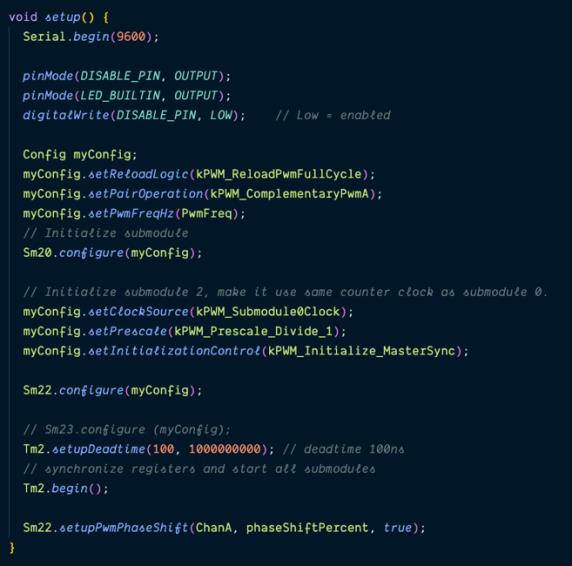
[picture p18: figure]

Figure 33: Section of inverter control code.

Figure 34: Inverter output with 50% phase shift.

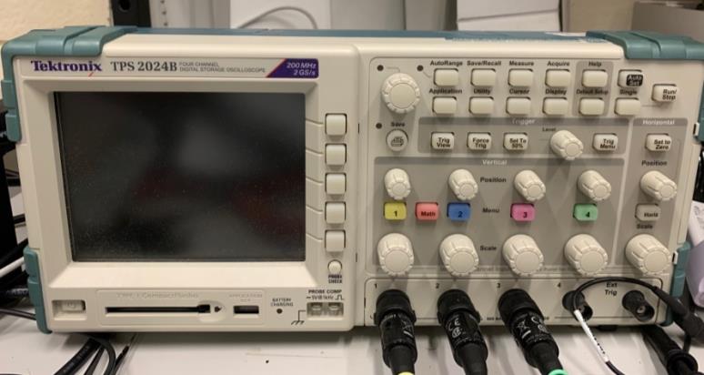
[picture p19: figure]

Figure 35: Tektronix TPS 2024B Oscilloscope.

### 4.3. Secondary and Primary Side Monitoring:

For the secondary side, an ESP32 is used in conjunction with a DC current sensor module, as

well as a DC voltage sensor module (shown in figure 36). These output analog signals, that

are sampled by the analog-to-digital converter (ADC) of the ESP32. This allows

measurement of the output voltage and current after the rectifier on the secondary side. This

is used for two things: 1) Detection of Rx coil, and 2) Feedback for voltage output from

inverter. The connections of the current and voltage sensor modules to the rectifier and the

ESP32 is shown in figure 37. At the time of writing this report, the primary side sensing has

not been implemented yet. However, the sensors for this have been identified, and integration

should be complete by the final presentation. These are shown in figure 38.

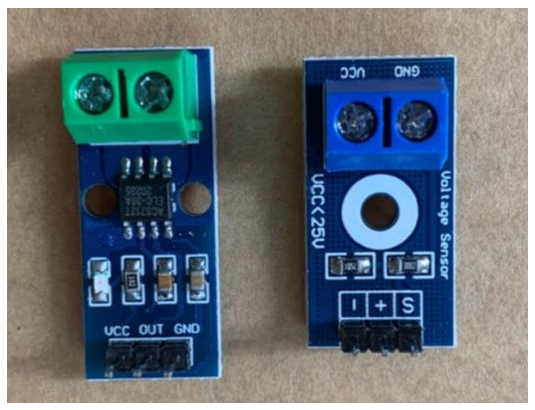
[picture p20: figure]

Figure 36: (Left) Current sensor module, (right) voltage sensor module.

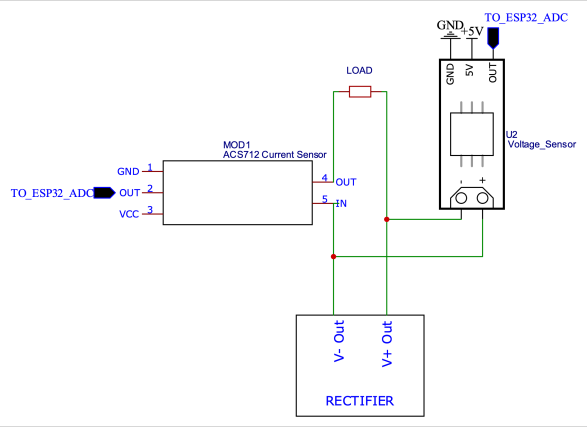
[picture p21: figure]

Figure 37: Connection of current/voltage sensor module to rectifier and ESP32.

Figure 38: AC voltage sensor (left), AC current sensor (right). Both will be used on the Tx coil.

### 4.4. Dashboard and Database:

At the time of writing of this report, only a rudimentary dashboard has been created, which

can show the voltage and current from the secondary side, as seen in Figure 39, as well as

control the on/off state of the primary side. This was made using the Dart programming

language and the Flutter framework. For the database, Firebase’s Realtime Database was

used, as seen in figure 40.

Figure 39: First version of the dashboard made with Flutter.

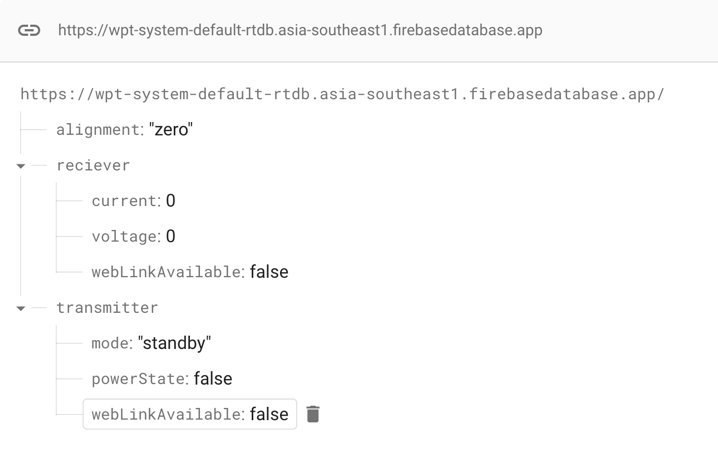
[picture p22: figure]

Figure 40: Schema of Firebase Realtime database used.

### 4.5. WPT System Testing:

Complete testing of the WTP system was done, and the efficiency of the system was

tabulated. The system setup is shown in figure 41. ACTIVE mode operation, is seen in figure

42 (a) where voltage is successfully induced in the Rx coil, indicating power transfer. Also

STANDBY mode, with its pulsing function was tested, and it works as expected. The

waveform produced in this mode is shown in figure 42 (b). The extreme condition of phase-

shift control was also tested and verified, where at 180 degrees phase shift, the waveform

cancels out, and the lowest output voltage possible is produced (figure 43).

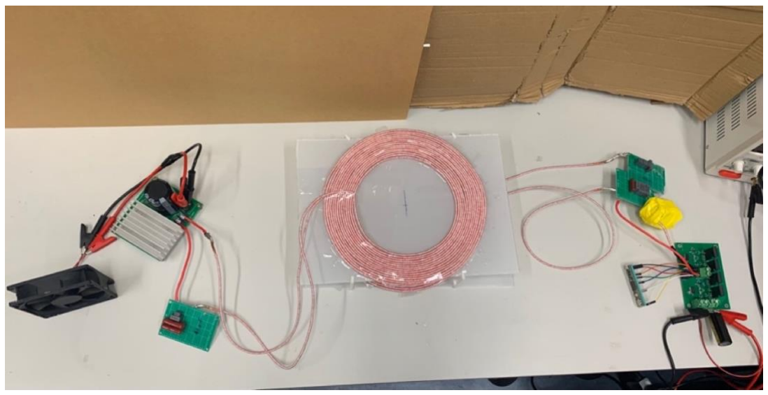
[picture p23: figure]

Figure 41: WPT system setup, with the primary side on the right, coils in the middle, and secondary side driving a 12V fan on the output.

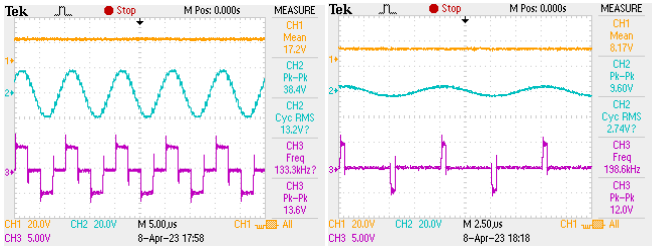
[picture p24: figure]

(a) (b)

Figure 42: (a) Inverter output waveform during ACTIVE mode (purple), secondary induced voltage (blue), and output DC voltage (orange). (b) shows the same waveforms during STANDBY mode.

Figure 43: 180 degree phase shift output waveform. Minimum output power.

To test the efficiency of the system, the system was made to supply power to shunt resistors

of known value. This allowed for the calculation of output power. Meanwhile, input power is

known as it is shown by the DC power supply. The efficiency was then calculated as

following:

η =

Pout

Pin

(14)

The efficiency results are shown in table 5. It can be seen that a maximum efficiency of ~64

% was achieved, with a power transfer of 75.15 W. Higher voltage/current testing was not

possible due to limitations of the lab bench power supply available.

Table 5: Efficiency results for WPT system under different load scenarios.

V out (V) I out (A) | P out (W) Vin (V) | I in (A)

load

| | | | | | (ohms) | P in (W) | efficiency
| | | | | | | | (%)
5 V test | 7.64 | 0.764 | 5.83696 | 5.04 | 2.31 | 10 | 11.6 | 50.14
10 V test | 20.6 | 1.03 | 21.218 | 10 | 3.25 | 20 | 32.5 | 65.29
15 V test | 36.3 | 0.726 | 26.3538 | 15 | 2.78 | 50 | 41.7 | 63.20
20 V test | 48.9 | 0.978 | 47.8242 | 20 | 3.72 | 50 | 74.4 | 64.28
25 V test | 61.3 | 1.226 | 75.1538 | 25 | 4.76 | 50 | 119 | 63.15

It should also be noted that when the Rx coil approached the Tx coil, the input waveform, and

the induced voltage waveform were affected. This is due to the change in mutual inductance,

and is a sign that the circuit is not properly compensated. This may occur due to small errors

in the values of the capacitance and inductance used in the LCC network. This change in

shape can be seen in figure 44.

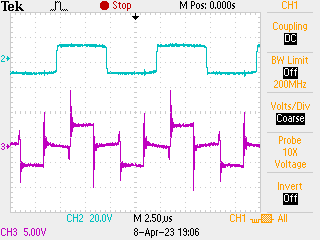
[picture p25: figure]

Figure 44: Change in shape of waveform under load. voltage induced in Rx (blue), and input waveform (purple).

## Chapter 5: Recommendations for Future Work:

My recommendations for future studies in the area of smart WPT systems:

1. Generalisation of the system described in this paper, so that it can be applied to many

more robots without significant modification to the parameters.

2. Explore the potential for scaling up the power transfer capacity of the system to

accommodate larger and more power-intensive robotic applications, as this was not

tested in the system in this paper.

3. Compare different IoT communication protocols (example: MQTT) to determine the

most suitable option for various robotics WPT applications.

4. Investigate the implementation of a multi-device WPT system that can simultaneously

charge several robots using the smart charging system.

5. Investigate the cybersecurity aspects of the IoT-integrated wireless charging system,

as a lot of information is being transmitted to the cloud in this application.

6. Explore how machine learning or artificial intelligence techniques may be

incorporated into the system for advanced monitoring and control capabilities, as well

as for predicting the charging patterns of the robot.

## Chapter 6: Conclusion:

In conclusion, this paper has successfully demonstrated the development and implementation

of a smart wireless charging system for robotics, utilizing LCC-S compensation and

integrating IoT technology for remote control, monitoring, and active feedback control. The

system was designed for the Hunter SE rover shows high potential for integration with other

robotic applications. With a maximum tested efficiency of 65% and a power transfer

capability of 75 W over a 4 cm air gap, and higher power transfer possible based on the

capabilities of the inverter, the smart wireless power transfer system stands out as a modern

alternative to traditional wired charging solutions. The paper also successfully met the target

of developing a truly smart WPT system that provides increased flexibility and convenience

for users with the availability of information through the online dashboard.

## Appendix:

Coil modelling extra information. These equations are used to calculate intermediate

parameters W and R in the modelling of coil inductance in 3.1.3:

W (width) | = | (

wire diameter
25.4

+ N ∙

wire spacing
25.4
) | (15 )
R (radius) | =

(

inner diameter
25.4

+ W)

2

(16)

## References:

[1] A. Marincic, “NIKOLA TESLA’S CONTRIBUTIONS TO RADIO
DEVELOPMENTS,” Heinrich Hertz Institute, Hamburg, Heinrich Hertz Institute, Hamburg, Oct. 2007, pp. 377–395. Accessed: Apr. 04, 2023. [Online]. Available: https://www.researchgate.net/publication/310801603_NIKOLA_TESLA%27S_CONTRIBUTIONS_TO_RADIO_DEVELOPMENTS
[2] A. Kurs, A. Karalis, R. Moffatt, J. D. Joannopoulos, P. Fisher, and M. Soljačić, “Wireless Power Transfer via Strongly Coupled Magnetic Resonances,” Science, vol. 317, no. 5834, pp. 83–86, Jul. 2007, doi: 10.1126/science.1143254.
[3] A. Kurs, “Power transfer through strongly coupled resonances,” Apr. 2009.
[4] A. Karalis, J. D. Joannopoulos, and M. Soljačić, “Efficient wireless non-radiative mid-range energy transfer,” Ann. Phys., vol. 323, no. 1, pp. 34–48, Jan. 2008, doi: 10.1016/j.aop.2007.04.017.
[5] M. Kesler, “Highly Resonant Wireless Power Transfer: Safe, Efficient, and over Distance,” 2013.
[6] S. A. Mirbozorgi, H. Bahrami, M. Sawan, and B. Gosselin, “A Smart Multicoil Inductively Coupled Array for Wireless Power Transmission,” IEEE Trans. Ind. Electron., vol. 61, no. 11, pp. 6061–6070, Nov. 2014, doi: 10.1109/TIE.2014.2308138.
[7] S. Y. Hui, “Planar Wireless Charging Technology for Portable Electronic Products and Qi,” Proc. IEEE, vol. 101, no. 6, pp. 1290–1301, Jun. 2013, doi: 10.1109/JPROC.2013.2246531.
[8] K. Li, U. Muncuk, M. Y. Naderi, and K. R. Chowdhury, “SoftCharge: Software Defined Multi-Device Wireless Charging Over Large Surfaces,” IEEE J. Emerg. Sel. Top. Circuits Syst., vol. 10, no. 1, pp. 38–51, Mar. 2020, doi:
10.1109/JETCAS.2020.2973814.
[9] N. Ha-Van, T. L. Vu, and M. Thuy Le, “An Efficient Wireless Power Transfer for Retinal Prosthesis using Artificial Intelligent Algorithm,” in 2020 50th European Microwave Conference (EuMC), Jan. 2021, pp. 1115–1118. doi: 10.23919/EuMC48046.2021.9338235.
[10] Y. Liu, C. Liu, R. Huang, and Z. Song, “Primary Multi-frequency Constant-current Compensation for One-to-multiple Wireless Power Transfer,” IEEE Trans. Circuits Syst. II Express Briefs, pp. 1–1, 2023, doi: 10.1109/TCSII.2023.3237078.
[11] X. Lu, D. Niyato, P. Wang, D. I. Kim, and Z. Han, “Wireless charger networking for mobile devices: fundamentals, standards, and applications,” IEEE Wirel. Commun., vol. 22, no. 2, pp. 126–135, Apr. 2015, doi: 10.1109/MWC.2015.7096295.
[12] Y. Zhou, C. Liu, and Y. Huang, “Wireless Power Transfer for Implanted Medical Application: A Review,” Energies, vol. 13, no. 11, Art. no. 11, Jan. 2020, doi: 10.3390/en13112837.
[13] D. Patil, M. K. McDonough, J. M. Miller, B. Fahimi, and P. T. Balsara, “Wireless Power Transfer for Vehicular Applications: Overview and Challenges,” IEEE Trans. Transp. Electrification, vol. 4, no. 1, pp. 3–37, Mar. 2018, doi: 10.1109/TTE.2017.2780627.
[14] S. Aldhaher, P. D. Mitcheson, J. M. Arteaga, G. Kkelis, and D. C. Yates, “Light-weight wireless power transfer for mid-air charging of drones,” in 2017 11th European Conference on Antennas and Propagation (EUCAP), Mar. 2017, pp. 336–340. doi: 10.23919/EuCAP.2017.7928799.

[15] M. Tampubolon, L. Pamungkas, H.-J. Chiu, Y.-C. Liu, and Y.-C. Hsieh, “Dynamic Wireless Power Transfer for Logistic Robots,” Energies, vol. 11, no. 3, Art. no. 3, Mar. 2018, doi: 10.3390/en11030527.
[16] W. C. Brown, “The History of Power Transmission by Radio Waves,” IEEE Trans. Microw. Theory Tech., vol. 32, no. 9, pp. 1230–1242, Sep. 1984, doi: 10.1109/TMTT.1984.1132833.
[17] W. Brown, “Experiments in the transportation of energy by microwave beam,” in 1958 IRE International Convention Record, Mar. 1964, pp. 8–17. doi: 10.1109/IRECON.1964.1147324.
[18] P. E. Glaser, “Power from the Sun: Its Future,” Science, vol. 162, no. 3856, pp. 857– 861, Nov. 1968, doi: 10.1126/science.162.3856.857.
[19] G. Mosca and P. A. Tipler, “27-4 Ampere’s Law,” in Physics for Scientists and Engineers, 5th ed.New York: W.H. Freeman, 2003, pp. 871–874.
[20] G. Mosca and P. A. Tipler, “28-2 Induced EMF and Faraday’s Law,” in Physics for Scientists and Engineers, 5th ed.New York: W.H. Freeman, 2003, pp. 899–902.
[21] J. Gubbi, R. Buyya, S. Marusic, and M. Palaniswami, “Internet of Things (IoT): A vision, architectural elements, and future directions,” Future Gener. Comput. Syst., vol. 29, no. 7, pp. 1645–1660, Sep. 2013, doi: 10.1016/j.future.2013.01.010.
[22] L. Atzori, A. Iera, and G. Morabito, “The Internet of Things: A survey,” Comput. Netw., vol. 54, no. 15, pp. 2787–2805, Oct. 2010, doi: 10.1016/j.comnet.2010.05.010.
[23] A. Azad, R. Tavakoli, U. Pratik, B. Varghese, C. Coopmans, and Z. Pantic, “A Smart Autonomous WPT System for Electric Wheelchair Applications With Free-Positioning Charging Feature,” IEEE J. Emerg. Sel. Top. Power Electron., vol. 8, no. 4, pp. 3516– 3532, Dec. 2020, doi: 10.1109/JESTPE.2018.2884887.
[24] C. R. Teeneti et al., “System-Level Approach to Designing a Smart Wireless Charging System for Power Wheelchairs,” IEEE Trans. Ind. Appl., vol. 57, no. 5, pp. 5128–5144, Sep. 2021, doi: 10.1109/TIA.2021.3093843.
[25] Y.-J. Kim, D. Ha, W. J. Chappell, and P. P. Irazoqui, “Selective Wireless Power Transfer for Smart Power Distribution in a Miniature-Sized Multiple-Receiver System,” IEEE Trans. Ind. Electron., vol. 63, no. 3, pp. 1853–1862, Mar. 2016, doi: 10.1109/TIE.2015.2493142.
[26] D. van Wageningen and T. Staring, “The Qi wireless power standard,” in Proceedings of 14th International Power Electronics and Motion Control Conference EPE-PEMC 2010, Sep. 2010, pp. S15-25-S15-32. doi: 10.1109/EPEPEMC.2010.5606673.
[27] W. C. Cheah, S. A. Watson, and B. Lennox, “Limitations of wireless power transfer technologies for mobile robots,” Wirel. Power Transf., vol. 6, no. 2, pp. 175–189, Sep. 2019, doi: 10.1017/wpt.2019.8.
[28] M. Aboualalaa, H. Elsadek, R. K. Pokharel, M. Aboualalaa, H. Elsadek, and R. K. Pokharel, WPT, Recent Techniques for Improving System Efficiency. IntechOpen, 2021. doi: 10.5772/intechopen.96003.
[29] H. A. Wheeler, “Simple Inductance Formulas for Radio Coils,” Proc. Inst. Radio Eng., vol. 16, no. 10, pp. 1398–1400, Oct. 1928, doi: 10.1109/JRPROC.1928.221309.
[30] “Spiral Coil Calculator,” Kaizer Power Electronics, Sep. 16, 2015. https://kaizerpowerelectronics.dk/calculators/spiral-coil-calculator/ (accessed Apr. 10, 2023).
[31] X. Qu, Y. Jing, H. Han, S.-C. Wong, and C. K. Tse, “Higher Order Compensation for Inductive-Power-Transfer Converters With Constant-Voltage or Constant-Current Output Combating Transformer Parameter Constraints,” IEEE Trans. Power Electron., vol. 32, no. 1, pp. 394–405, Jan. 2017, doi: 10.1109/TPEL.2016.2535376.

[32] Y. Chen, H. Zhang, C.-S. Shin, K.-H. Seo, S.-J. Park, and D.-H. Kim, “A Comparative Study of S-S and LCC-S Compensation Topology of Inductive Power Transfer Systems for EV Chargers,” in 2019 IEEE 10th International Symposium on Power Electronics for Distributed Generation Systems (PEDG), Jun. 2019, pp. 99–104. doi: 10.1109/PEDG.2019.8807684.
[33] J. Yang, X. Zhang, K. Zhang, X. Cui, C. Jiao, and X. Yang, “Design of LCC-S Compensation Topology and Optimization of Misalignment Tolerance for Inductive Power Transfer,” IEEE Access, vol. 8, pp. 191309–191318, 2020, doi: 10.1109/ACCESS.2020.3032563.
[34] M. Abou Houran, xu Yang, and W. Chen, “Magnetically Coupled Resonance WPT: Review of Compensation Topologies, Resonator Structures with Misalignment, and EMI Diagnostics,” vol. 7, Nov. 2018, doi: 10.3390/electronics7110296.
[35] “Phase-Shifted Full Bridge DC/DC Power Converter Design Guide,” 2014.
[36] “i.MX RT1060 Processor Reference Manual.” [Online]. Available: https://www.pjrc.com/teensy/IMXRT1060RM_rev3.pdf
[37] “CyberDog Bionic Quadruped Robot,” Xiaomi. https://www.mi.com/cyberdog/gallery (accessed Apr. 10, 2023).
[38] “HUNTER SE Rover,” Agilex Robotics. https://global.agilex.ai/products/hunter-se (accessed Apr. 10, 2023).
[39] “Hunter SE.” https://www.trossenrobotics.com/hunter-se.aspx (accessed Apr. 10, 2023).
[40] “XIII. On electrical motions in a spherical conductor,” Philos. Trans. R. Soc. Lond., vol. 174, pp. 519–549, Dec. 1883, doi: 10.1098/rstl.1883.0013.
[41] Y. P. Su, X. Liu, and S. Y. R. Hui, “Mutual Inductance Calculation of Movable Planar Coils on Parallel Surfaces,” IEEE Trans. Power Electron., vol. 24, no. 4, pp. 1115– 1123, Apr. 2009, doi: 10.1109/TPEL.2008.2009757.
[42] “Teensy® 4.1.” https://www.pjrc.com/store/teensy41.html (accessed Apr. 11, 2023).
[43] “LAUNCHXL-F28379D Development kit | TI.com.”
https://www.ti.com/tool/LAUNCHXL-F28379D (accessed Apr. 11, 2023).
[44] “eFlexPwm: eFlexPwm.” https://epsilonrt.github.io/eFlexPwm/ (accessed Apr. 11, 2023).

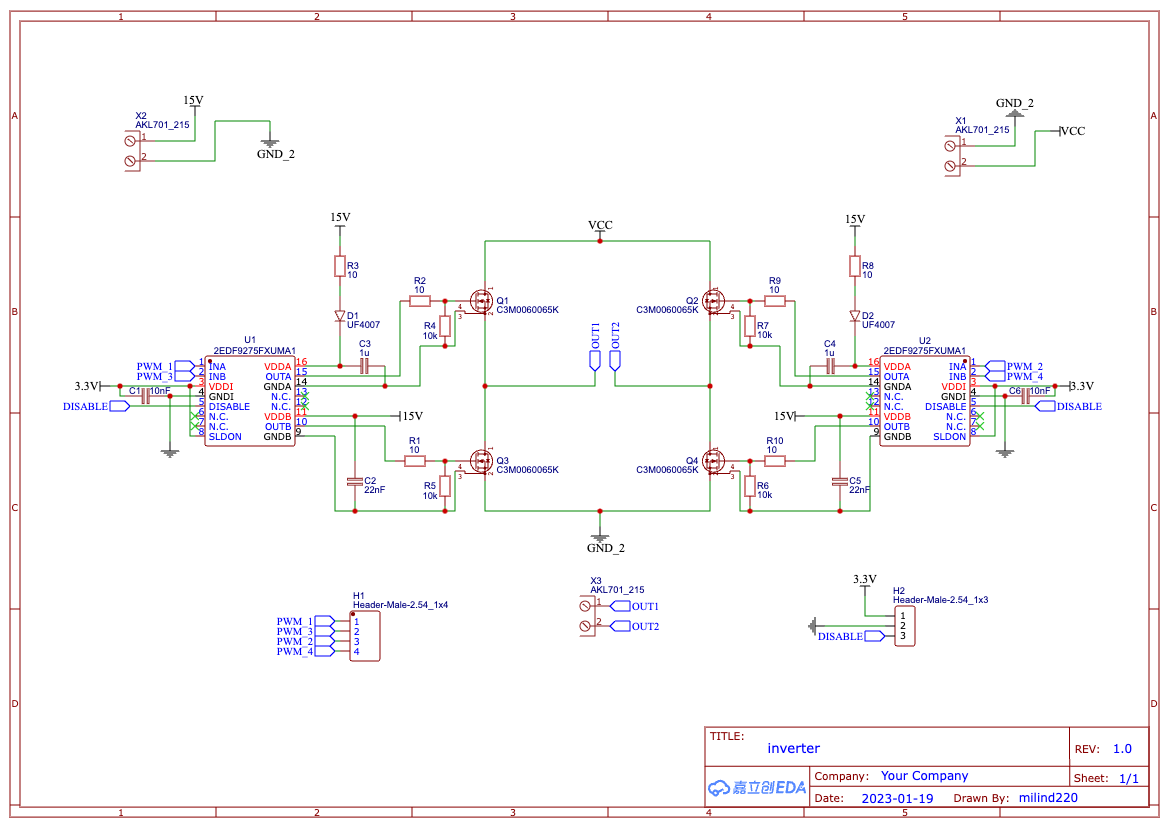
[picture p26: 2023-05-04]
Hardware/Inverter/Inverter_schematic_picture.png

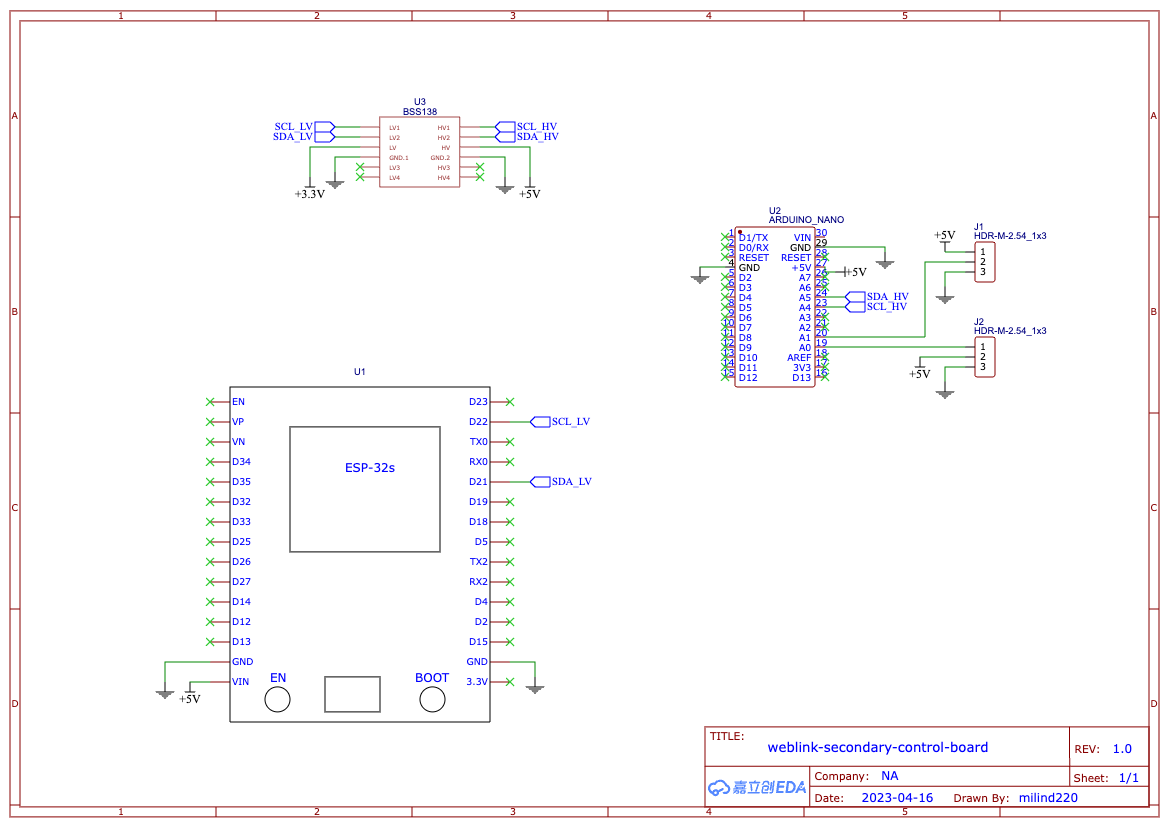
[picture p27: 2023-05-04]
Hardware/Secondary Side Control Board/Schematic_weblink-secondary.png

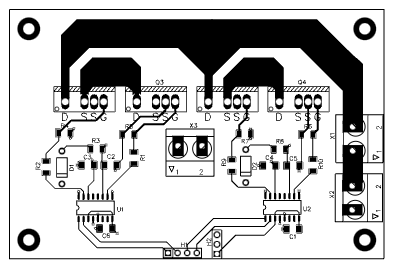
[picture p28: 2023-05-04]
Hardware/Inverter/Inverter_PCB_picture.png

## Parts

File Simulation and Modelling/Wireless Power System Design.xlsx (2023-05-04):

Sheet: General Design
Charging End Requirements
Nominal Voltage (V) | Max Current (A) | Output Power (W) |  |  |  | General Constants |  |  | Coil Voltage-Current Relationships
24 | 10 | 240 |  |  |  | Coil separation | 0.1 | m
 |  |  |  |  |  | sec./pri. ratio | 1
DC-DC Boost Converter Characteristics |  |  |  |  |  | µ0 | 1.256637061e-06 | H/m
Efficiency (%) | Vin (V) | Vout (V) | P in (W) | P out (W) |  | µr copper | 0.999994
 |  |  |  |  |  | µr air | 1
Rectifier Characteristics |  |  |  |  |  | System Constants
Diode Fwd. V. drop (V) | Power Losses (W) | Total V drop (V) | AC V in. (V) | Power In |  | Operating freq. | 100 | kHz
1.875 | 0 | 3.75 | 27.75 | 240 |  | Coil Seperation Distance | 4
 |  |  |  |  |  | Mutual Inductance | 25.465 | µH
Coil Characteristics |  |  |  |  |  | Coupling Factor k | 0.4172891747
Theoretical Characteristics |  |  |  |  |  | Skin effect | 206.17 | µm
 | Secondary Coil | Primary Coil | Unit
Shape | spiral planar | spiral planar |  |  |  | Litz Wire Characteristics
Outer diameter | 230 | 230 | mm |  |  | Type | 0.1 x 350
No. of turns | 15 | 15 |  |  |  | resistance/m | 9.686 | mOhm/m
Turn spacing | 0.5 | 0.5 | mm |  |  | wire diameter | 2.47 | mm
wire length (approx) | 8.74 | 8.74 | m |  |  | copper resistivity | 1.678e-08 | Ohm m
Inner diameter | 140.90 | 140.90 | mm |  |  | strand diameter | 100 | µm
Coil area | 0.04 | 0.04 | m^2
Inductance L | 61.83 | 61.83 | µH |  |  | Compensation Network
capacitance (nF) | 40.00 | 40.00 | nF |  |  | Lp | 5 | µH
Resonant frequency | 101.20 | 101.20 | kHz |  |  | Cp | 506.61 | nF
width (hidden) | 1.75 | 1.75 |  |  |  | Ct | 45.33 | nF
radius (hidden) | 3.65 | 3.65 |  |  |  | Cr | 41.41 | nF
Measured Characteristics
Series inductance Ls | 61.17 | 60.88 | µH
Series resistance Rs | 85 | 84.3 | mOHm
Req. resonant freqency | 100 | 100 | kHz
Required capacitance | 41.40967126 | 41.60692495 | nF
Mutual Inductance Measurements
Spacer height (cm) | Ls + Lp + 2M | Ls + Lp - 2M | M | unit | coupling factor k
0 | 224.08 | 14.78 | 52.325 | µH | 0.8574
2 | 193.35 | 40.46 | 38.2225 | µH | 0.6263
4 | 168.55 | 66.69 | 25.465 | µH | 0.4173
6 | 154.16 | 84.21 | 17.4875 | µH | 0.2866
8 | 144.65 | 94.3 | 12.5875 | µH | 0.2063
10 | 137.83 | 101.06 | 9.1925 | µH | 0.1506
 |  |  |  |  |  |  |  |  |  | source for calculation of inductance etc: https://kaizerpowerelectronics.dk/calculators/spiral-coil-calculator/

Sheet: Sheet5
Coil Characteristics
Outer diameter | 230 | 230 | 230 | 230 | 230 | 230 | 230 | 230 | 230 | 230 | 230 | 230 | 230 | 230 | 230 | 230 | 230 | 230 | 230 | 230 | 230 | 230 | 230 | 230 | 230 | 230 | 230 | 230 | 230 | 230 | 230 | 230 | 230 | 230 | 230 | 230 | 230 | 230
No. of turns | 1 | 2 | 3 | 4 | 5 | 6 | 7 | 8 | 9 | 10 | 11 | 12 | 13 | 14 | 15 | 16 | 17 | 18 | 19 | 20 | 21 | 22 | 23 | 24 | 25 | 26 | 27 | 28 | 29 | 30 | 31 | 32 | 33 | 34 | 35 | 36 | 37 | 38
wire length (approx) | 0.71 | 1.41 | 2.08 | 2.74 | 3.38 | 4.00 | 4.60 | 5.18 | 5.75 | 6.29 | 6.82 | 7.33 | 7.82 | 8.29 | 8.74 | 9.17 | 9.59 | 9.98 | 10.36 | 10.72 | 11.06 | 11.38 | 11.68 | 11.97 | 12.23 | 12.48 | 12.71 | 12.92 | 13.11 | 13.28 | 13.43 | 13.57 | 13.68 | 13.78 | 13.86 | 13.92 | 13.96 | 13.98
Inner diameter | 224.06 | 218.12 | 212.18 | 206.24 | 200.30 | 194.36 | 188.42 | 182.48 | 176.54 | 170.60 | 164.66 | 158.72 | 152.78 | 146.84 | 140.90 | 134.96 | 129.02 | 123.08 | 117.14 | 111.20 | 105.26 | 99.32 | 93.38 | 87.44 | 81.50 | 75.56 | 69.62 | 63.68 | 57.74 | 51.80 | 45.86 | 39.92 | 33.98 | 28.04 | 22.10 | 16.16 | 10.22 | 4.28
Coil area | 0.04 | 0.04 | 0.04 | 0.04 | 0.04 | 0.04 | 0.04 | 0.04 | 0.04 | 0.04 | 0.04 | 0.04 | 0.04 | 0.04 | 0.04 | 0.04 | 0.04 | 0.04 | 0.04 | 0.04 | 0.04 | 0.04 | 0.04 | 0.04 | 0.04 | 0.04 | 0.04 | 0.04 | 0.04 | 0.04 | 0.04 | 0.04 | 0.04 | 0.04 | 0.04 | 0.04 | 0.04 | 0.04
Inductance L | 0.54 | 2.06 | 4.41 | 7.47 | 11.12 | 15.27 | 19.81 | 24.66 | 29.75 | 35.01 | 40.37 | 45.78 | 51.19 | 56.55 | 61.83 | 66.98 | 71.98 | 76.79 | 81.40 | 85.78 | 89.91 | 93.77 | 97.36 | 100.65 | 103.65 | 106.33 | 108.71 | 110.77 | 112.50 | 113.92 | 115.02 | 115.80 | 116.27 | 116.42 | 116.27 | 115.82 | 115.07 | 114.05
resistance R | 6.908401766 | 13.6360525 | 20.18295221 | 26.54910088 | 32.73449853 | 38.73914514 | 44.56304072 | 50.20618527 | 55.66857879 | 60.95022128 | 66.05111274 | 70.97125317 | 75.71064257 | 80.26928094 | 84.64716828 | 88.84430458 | 92.86068986 | 96.6963241 | 100.3512073 | 103.8253395 | 107.1187207 | 110.2313508 | 113.1632299 | 115.9143579 | 118.484735 | 120.874361 | 123.0832359 | 125.1113599 | 126.9587328 | 128.6253547 | 130.1112255 | 131.4163453 | 132.5407141 | 133.4843319 | 134.2471986 | 134.8293143 | 135.2306789 | 135.4512926
width (hidden) | 0.12 | 0.23 | 0.35 | 0.47 | 0.58 | 0.70 | 0.82 | 0.94 | 1.05 | 1.17 | 1.29 | 1.40 | 1.52 | 1.64 | 1.75 | 1.87 | 1.99 | 2.10 | 2.22 | 2.34 | 2.46 | 2.57 | 2.69 | 2.81 | 2.92 | 3.04 | 3.16 | 3.27 | 3.39 | 3.51 | 3.62 | 3.74 | 3.86 | 3.98 | 4.09 | 4.21 | 4.33 | 4.44
radius (hidden) | 4.47 | 4.41 | 4.35 | 4.29 | 4.24 | 4.18 | 4.12 | 4.06 | 4.00 | 3.94 | 3.88 | 3.83 | 3.77 | 3.71 | 3.65 | 3.59 | 3.53 | 3.48 | 3.42 | 3.36 | 3.30 | 3.24 | 3.18 | 3.12 | 3.07 | 3.01 | 2.95 | 2.89 | 2.83 | 2.77 | 2.72 | 2.66 | 2.60 | 2.54 | 2.48 | 2.42 | 2.36 | 2.31
 | turn spacing | 0.5 | mm
 | diameter | 2.47 | mm
 | resistance/m | 9.686 | mOhm/m
 |  |  |  |  |  |  |  |  |  |  |  |  |  |  |  |  | Outer diameter | No. of turns | wire length (approx) | Inner diameter | Coil area | Inductance L | resistance R | width (hidden) | radius (hidden)
 |  |  |  |  |  |  |  |  |  |  |  |  |  |  |  |  | 230 | 1 | 0.71 | 224.06 | 0.04 | 0.54 | 6.908401766 | 0.12 | 4.47
 |  |  |  |  |  |  |  |  |  |  |  |  |  |  |  |  | 230 | 2 | 1.41 | 218.12 | 0.04 | 2.06 | 13.6360525 | 0.23 | 4.41
 |  |  |  |  |  |  |  |  |  |  |  |  |  |  |  |  | 230 | 3 | 2.08 | 212.18 | 0.04 | 4.41 | 20.18295221 | 0.35 | 4.35
 |  |  |  |  |  |  |  |  |  |  |  |  |  |  |  |  | 230 | 4 | 2.74 | 206.24 | 0.04 | 7.47 | 26.54910088 | 0.47 | 4.29
 |  |  |  |  |  |  |  |  |  |  |  |  |  |  |  |  | 230 | 5 | 3.38 | 200.30 | 0.04 | 11.12 | 32.73449853 | 0.58 | 4.24
 |  |  |  |  |  |  |  |  |  |  |  |  |  |  |  |  | 230 | 6 | 4.00 | 194.36 | 0.04 | 15.27 | 38.73914514 | 0.70 | 4.18
 |  |  |  |  |  |  |  |  |  |  |  |  |  |  |  |  | 230 | 7 | 4.60 | 188.42 | 0.04 | 19.81 | 44.56304072 | 0.82 | 4.12
 |  |  |  |  |  |  |  |  |  |  |  |  |  |  |  |  | 230 | 8 | 5.18 | 182.48 | 0.04 | 24.66 | 50.20618527 | 0.94 | 4.06
 |  |  |  |  |  |  |  |  |  |  |  |  |  |  |  |  | 230 | 9 | 5.75 | 176.54 | 0.04 | 29.75 | 55.66857879 | 1.05 | 4.00
 |  |  |  |  |  |  |  |  |  |  |  |  |  |  |  |  | 230 | 10 | 6.29 | 170.60 | 0.04 | 35.01 | 60.95022128 | 1.17 | 3.94
 |  |  |  |  |  |  |  |  |  |  |  |  |  |  |  |  | 230 | 11 | 6.82 | 164.66 | 0.04 | 40.37 | 66.05111274 | 1.29 | 3.88
 |  |  |  |  |  |  |  |  |  |  |  |  |  |  |  |  | 230 | 12 | 7.33 | 158.72 | 0.04 | 45.78 | 70.97125317 | 1.40 | 3.83
 |  |  |  |  |  |  |  |  |  |  |  |  |  |  |  |  | 230 | 13 | 7.82 | 152.78 | 0.04 | 51.19 | 75.71064257 | 1.52 | 3.77
 |  |  |  |  |  |  |  |  |  |  |  |  |  |  |  |  | 230 | 14 | 8.29 | 146.84 | 0.04 | 56.55 | 80.26928094 | 1.64 | 3.71
 |  |  |  |  |  |  |  |  |  |  |  |  |  |  |  |  | 230 | 15 | 8.74 | 140.90 | 0.04 | 61.83 | 84.64716828 | 1.75 | 3.65
 |  |  |  |  |  |  |  |  |  |  |  |  |  |  |  |  | 230 | 16 | 9.17 | 134.96 | 0.04 | 66.98 | 88.84430458 | 1.87 | 3.59
 |  |  |  |  |  |  |  |  |  |  |  |  |  |  |  |  | 230 | 17 | 9.59 | 129.02 | 0.04 | 71.98 | 92.86068986 | 1.99 | 3.53
 |  |  |  |  |  |  |  |  |  |  |  |  |  |  |  |  | 230 | 18 | 9.98 | 123.08 | 0.04 | 76.79 | 96.6963241 | 2.10 | 3.48
 |  |  |  |  |  |  |  |  |  |  |  |  |  |  |  |  | 230 | 19 | 10.36 | 117.14 | 0.04 | 81.40 | 100.3512073 | 2.22 | 3.42
 |  |  |  |  |  |  |  |  |  |  |  |  |  |  |  |  | 230 | 20 | 10.72 | 111.20 | 0.04 | 85.78 | 103.8253395 | 2.34 | 3.36
 |  |  |  |  |  |  |  |  |  |  |  |  |  |  |  |  | 230 | 21 | 11.06 | 105.26 | 0.04 | 89.91 | 107.1187207 | 2.46 | 3.30
 |  |  |  |  |  |  |  |  |  |  |  |  |  |  |  |  | 230 | 22 | 11.38 | 99.32 | 0.04 | 93.77 | 110.2313508 | 2.57 | 3.24
 |  |  |  |  |  |  |  |  |  |  |  |  |  |  |  |  | 230 | 23 | 11.68 | 93.38 | 0.04 | 97.36 | 113.1632299 | 2.69 | 3.18
 |  |  |  |  |  |  |  |  |  |  |  |  |  |  |  |  | 230 | 24 | 11.97 | 87.44 | 0.04 | 100.65 | 115.9143579 | 2.81 | 3.12
 |  |  |  |  |  |  |  |  |  |  |  |  |  |  |  |  | 230 | 25 | 12.23 | 81.50 | 0.04 | 103.65 | 118.484735 | 2.92 | 3.07
 |  |  |  |  |  |  |  |  |  |  |  |  |  |  |  |  | 230 | 26 | 12.48 | 75.56 | 0.04 | 106.33 | 120.874361 | 3.04 | 3.01
 |  |  |  |  |  |  |  |  |  |  |  |  |  |  |  |  | 230 | 27 | 12.71 | 69.62 | 0.04 | 108.71 | 123.0832359 | 3.16 | 2.95
 |  |  |  |  |  |  |  |  |  |  |  |  |  |  |  |  | 230 | 28 | 12.92 | 63.68 | 0.04 | 110.77 | 125.1113599 | 3.27 | 2.89
 |  |  |  |  |  |  |  |  |  |  |  |  |  |  |  |  | 230 | 29 | 13.11 | 57.74 | 0.04 | 112.50 | 126.9587328 | 3.39 | 2.83
 |  |  |  |  |  |  |  |  |  |  |  |  |  |  |  |  | 230 | 30 | 13.28 | 51.80 | 0.04 | 113.92 | 128.6253547 | 3.51 | 2.77
 |  |  |  |  |  |  |  |  |  |  |  |  |  |  |  |  | 230 | 31 | 13.43 | 45.86 | 0.04 | 115.02 | 130.1112255 | 3.62 | 2.72
 |  |  |  |  |  |  |  |  |  |  |  |  |  |  |  |  | 230 | 32 | 13.57 | 39.92 | 0.04 | 115.80 | 131.4163453 | 3.74 | 2.66
 |  |  |  |  |  |  |  |  |  |  |  |  |  |  |  |  | 230 | 33 | 13.68 | 33.98 | 0.04 | 116.27 | 132.5407141 | 3.86 | 2.60
 |  |  |  |  |  |  |  |  |  |  |  |  |  |  |  |  | 230 | 34 | 13.78 | 28.04 | 0.04 | 116.42 | 133.4843319 | 3.98 | 2.54
 |  |  |  |  |  |  |  |  |  |  |  |  |  |  |  |  | 230 | 35 | 13.86 | 22.10 | 0.04 | 116.27 | 134.2471986 | 4.09 | 2.48
 |  |  |  |  |  |  |  |  |  |  |  |  |  |  |  |  | 230 | 36 | 13.92 | 16.16 | 0.04 | 115.82 | 134.8293143 | 4.21 | 2.42
 |  |  |  |  |  |  |  |  |  |  |  |  |  |  |  |  | 230 | 37 | 13.96 | 10.22 | 0.04 | 115.07 | 135.2306789 | 4.33 | 2.36
 |  |  |  |  |  |  |  |  |  |  |  |  |  |  |  |  | 230 | 38 | 13.98 | 4.28 | 0.04 | 114.05 | 135.4512926 | 4.44 | 2.31

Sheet: Testing
Efficiency Test
 | V out (V) | I out (A) | P out (W) | Vin (V) | I in (A) | load (ohms) | P in (W) | efficiency (%)
5 V test | 7.64 | 0.764 | 5.83696 | 5.04 | 2.31 | 10 | 11.6424 | 50.14
10 V test | 20.6 | 1.03 | 21.218 | 10 | 3.25 | 20 | 32.5 | 65.29
15 V test | 36.3 | 0.726 | 26.3538 | 15 | 2.78 | 50 | 41.7 | 63.20
20 V test | 48.9 | 0.978 | 47.8242 | 20 | 3.72 | 50 | 74.4 | 64.28
25 V test | 61.3 | 1.226 | 75.1538 | 25 | 4.76 | 50 | 119 | 63.15
open circuit | 36 | 0 | 0 | 10 | 0.137 | INF | 1.37 | 0
short circuit | 0 | 1.86 | 0 | 5 | 4.6 | 0 | 23 | 0
open circuit | 18.3 | 0 | 0 | 5 | 0.137 | INF | 0.685 | 0
short circuit | 0 | 1.86 | 0 | 5 | 4.6 | 0 | 23 | 0
 | #VALUE! | 41.607

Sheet: Comp. Network Capacitances
Cp | 506.61 | Ct | 45.33 | Cr | 41.41
Remaining | 3.13 | Remaining | 0.02 | Remaining | -0.05
Result | 503.48 | Result | 45.31 | Result | 41.46
C1 | 224.03 | C1 | 9.56 | C1 | 9.96
C2 | 223.14 | C2 | 9.58 | C2 | 10.01
C3 | 32.59 | C3 | 9.83 | C3 | 15.22
C4 | 15.07 | C4 | 9.55 | C4 | 6.27
 | 492.8 |  | 38.55
C5 | 7.32 | C5 | 4.56
C6 | 3.36 | C6 | 2.2
C7 | 0

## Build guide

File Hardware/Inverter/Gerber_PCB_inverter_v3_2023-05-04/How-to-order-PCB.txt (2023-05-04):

How to Order PCB

Please refer to:
https://docs.easyeda.com/en/PCB/Order-PCB

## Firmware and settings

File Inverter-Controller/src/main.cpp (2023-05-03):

#include <eFlexPwm.h>    // Version: 0.2.5
#include <Arduino.h>
#include <PID_v1.h>
#include <Wire.h>

// Pin definitions
#define DISABLE_PIN 24   // Used to disable/enable gate driver IC's outputs. low = enable, high = disable.
#define READ_MODE_PIN_0 36    // Used to read the 0 bit of the mode
#define READ_MODE_PIN_1 37    // Used to read the 1 bit of the mode

#define STANDBY_PHASE_SHIFT 20    // Small phase shift value for the standby mode.
#define OFFLINE_PHASE_SHIFT 50    // 50% or 90 degrees for offline standard mode.
#define DEADTIME_NS 100    // deadtime in nanoseconds.

// Phase shift range configuration
#define MIN_OUTPUT_PS 25   // phase shift value that results in min inverter output
#define MAX_OUTPUT_PS 0    // phase shift value that results in max inverter output

enum modes{
  OFF = 0,
  STANDBY = 1,
  ACTIVE = 2,
  OFFLINE = 3,
};

uint16_t volt = 0;
uint16_t sp_int = 0;
float voltageS = 0.0;
float sp = 0.0;
byte a, b, c, d, e;

// declare the funcs
uint32_t runOffMode();
uint32_t runStandbyMode();
uint32_t runOfflineMode();

uint32_t delayMicros = 0; // delay time in microseconds.
uint8_t mode = OFFLINE;
const uint32_t PwmFreq = 100000; // frequency of PWM = 100 kHz

// Add PID things
// Define Variables we'll be connecting to
double Setpoint, Input, Output;
//Specify the links and initial tuning parameters
double Kp=1, Ki=0, Kd=0;
PID myPID(&Input, &Output, &Setpoint, Kp, Ki, Kd, DIRECT);

using namespace eFlex;
// eFlexPWM submodules (Hardware -> PWM2: SM[0], SM[2]
SubModule Sm20(4, 33);
SubModule Sm22(6, 9);
//  Tm2 simplifies access to the functions that concern all the sub-modules
Timer &Tm2 = Sm20.timer();

void setup() {
  Serial.begin(9600);
  Wire.begin(); 
  Wire.setSCL(18);
  Wire.setSDA(19);
  Wire.setClock(100000);

  pinMode(DISABLE_PIN, OUTPUT);
  pinMode(LED_BUILTIN, OUTPUT);    // Temporarily used as a mode indicator. off = OFF, blink = STANDBY, on = ACTIVE, strobe = OFFLINE.
  // For the read mode pins, default is LOW. Should result in OFF mode in case of no input.
  pinMode(READ_MODE_PIN_0, INPUT_PULLDOWN);
  pinMode(READ_MODE_PIN_1, INPUT_PULLDOWN);

  digitalWrite(DISABLE_PIN, HIGH);    // high = disable, low = enable

  Config myConfig;
  myConfig.setReloadLogic(kPWM_ReloadPwmFullCycle);
  myConfig.setPairOperation(kPWM_ComplementaryPwmA);
  myConfig.setPwmFreqHz(PwmFreq); 
  // Initialize submodule
  Sm20.configure(myConfig);
 
  // Initialize submodule 2, make it use same counter clock as submodule 0. 
  myConfig.setClockSource(kPWM_Submodule0Clock);
  myConfig.setPrescale(kPWM_Prescale_Divide_1);
  myConfig.setInitializationControl(kPWM_Initialize_MasterSync);
  
  Sm22.configure(myConfig);
  
  // Sm23.configure (myConfig);
  Tm2.setupDeadtime(DEADTIME_NS, 1000000000); // deadtime 100 ns
  // synchronize registers and start all submodules
  Tm2.begin();

  Sm22.setupPwmPhaseShift(ChanA, STANDBY_PHASE_SHIFT, true); 

  // Wire.onReceive(handler);
}

unsigned long previousMillis = 0UL;
 
void loop() {
  unsigned long currentMillis = millis();
  Wire.requestFrom(9, 5);
  Serial.println("Requested!");

  a = Wire.read();
  b = Wire.read();
  c = Wire.read();
  d = Wire.read();
  e = Wire.read();

  volt = a;
  volt = (volt << 8) | b;
  sp_int = c;
  sp_int = (sp_int << 8) | d;

  // print voltage and current
  voltageS = float(volt) / 100.0;
  sp = float(sp_int) / 100.0;


  //print values
  Serial.print("S Voltage: ");
  Serial.print(voltageS);
  Serial.print(" | setpoint: ");
  Serial.println(sp);

  // Check mode
  mode = e;
  Serial.println(mode);
  // mode = OFFLINE;
  
  // Run the mode
  switch (mode) {
    case OFF:
      runOffMode();
      break;

    case STANDBY:
      // run every 500 ms
      if (currentMillis - previousMillis >= 500) {
        // save the last time you blinked the LED
        previousMillis = currentMillis;
        runStandbyMode();
      }
      // delayMicros = runStandbyMode();
      break;

    case ACTIVE:
    // run every 10 ms
      if (currentMillis - previousMillis >= 10) {
        // save the last time you blinked the LED
        Serial.printf("{%s, %d}: mode: ACTIVE\n", __FILE__, __LINE__);

        digitalWrite(DISABLE_PIN, LOW);    // MOSFET driver IC outputs enabled.
        digitalWrite(LED_BUILTIN, HIGH);   // LED on continuously.

        myPID.Compute();    // Compute PID loop and set output value.

        // scale PID output between min and max output phase shift values.
        Sm22.setupPwmPhaseShift(ChanA, map(Output, 0, 255, MIN_OUTPUT_PS, MAX_OUTPUT_PS), true);

        // delayMicros = (1000000U / PwmFreq) * 100; // delay 100 PWM periods
        previousMillis = currentMillis;
        
      }
      break;

    case OFFLINE:
    // run every 100 ms
      if (currentMillis - previousMillis >= 100) {
        // save the last time you blinked the LED
        previousMillis = currentMillis;
        runOfflineMode();
      }
      break;

    default:
      runOffMode();
      break;
  }
  // delayMicroseconds(delayMicros);   // loop delay for stability.
  delay(50);
}

uint32_t runOffMode() {
  // Switch off inverter.
  Serial.printf("{%s, %d}: mode: OFF\n", __FILE__, __LINE__);
  digitalWrite(DISABLE_PIN, HIGH);  // disables MOSFET driver ICs output.
  digitalWrite(LED_BUILTIN, LOW);   // Visual indication of mode. LED if off.
  return 0;
}

uint32_t runStandbyMode() { 
  // Switch on inverter in standby mode. This increases phase shift, pulses the output every 500ms, reduces power consumption.
  Serial.printf("{%s, %d}: mode: STANDBY\n", __FILE__, __LINE__);
  digitalWrite(DISABLE_PIN, !digitalRead(DISABLE_PIN));    // Toggles inverter output.
  digitalWrite(LED_BUILTIN, !digitalRead(LED_BUILTIN));   // Visual indication of mode. LED blinks.
  Sm22.setupPwmPhaseShift(ChanA, STANDBY_PHASE_SHIFT, true);
  return 500000;    // 500ms
}

uint32_t runOfflineMode() {
  Serial.printf("{%s, %d}: mode: OFFLINE\n", __FILE__, __LINE__);
  digitalWrite(DISABLE_PIN, LOW);
  digitalWrite(LED_BUILTIN, !digitalRead(LED_BUILTIN));   // Visual indication of mode. LED blinks.
  Sm22.setupPwmPhaseShift(ChanA, OFFLINE_PHASE_SHIFT, true);
  return 50000;    // 100ms
}

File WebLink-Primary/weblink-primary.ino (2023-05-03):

#include <WiFi.h>
#include <Firebase_ESP_Client.h>
#include "addons/TokenHelper.h"
#include "addons/RTDBHelper.h"
#include <Wire.h>
#include "config.h"

#define LED_BUILTIN 2    // Used to provide visual indicator of mode.

//Define Firebase Data object
FirebaseData fbdo;
FirebaseAuth auth;
FirebaseConfig config;

unsigned long sendDataPrevMillis = 0;    // Used to ensure that sending of data is stable and not too frequent.
int count = 0;
bool signupOK = false;

float voltageS = 0.0;    // Secondary side voltage read from firebase database.
float setpoint = 0.0;    // Target voltage setpoint to send to inverter controller.
uint8_t mode = 3;   // OFFLINE MODE
unsigned long modeChangeMillis = 0UL;    // used to ensure that mode change from STANDBY to ACTIVE is stable.

uint16_t volt_i2c = 0;
uint16_t setpoint_i2c = 0;

void handler();

void setup(){
  pinMode(LED_BUILTIN, OUTPUT);
  digitalWrite(LED_BUILTIN, LOW);

  Serial.begin(9600);
  Wire.begin(9);
  Wire.setClock(100000);

  WiFi.begin(WIFI_SSID, WIFI_PASSWORD);
  Serial.print("Connecting to Wi-Fi");
  while (WiFi.status() != WL_CONNECTED){
    Serial.print(".");
    delay(300);
  }
  Serial.println();
  Serial.print("Connected with IP: ");
  Serial.println(WiFi.localIP());
  Serial.println();

  /* Assign the api key (required) */
  config.api_key = API_KEY;

  /* Assign the RTDB URL (required) */
  config.database_url = DATABASE_URL;

  /* Sign up */
  if (Firebase.signUp(&config, &auth, "", "")){
    Serial.println("sign up ok");
    signupOK = true;
  }
  else{
    Serial.printf("%s\n", config.signer.signupError.message.c_str());
  }

  /* Assign the callback function for the long running token generation task */
  config.token_status_callback = tokenStatusCallback; //see addons/TokenHelper.h
  
  Firebase.begin(&config, &auth);
  Firebase.reconnectWiFi(true);
  Serial.println("setup complete");
}

void loop() {
  // on i2c request, send data to inverter controller
  Wire.onRequest(handler);

  if (Firebase.ready() && signupOK && (millis() - sendDataPrevMillis > 50 || sendDataPrevMillis == 0)) {
    sendDataPrevMillis = millis();
    if (Firebase.RTDB.getFloat(&fbdo, "/receiver/voltage")) {
      Serial.println(fbdo.dataType());
      // if (fbdo.dataType() == "float") {
        Serial.print("assigning voltage: ");
        voltageS = fbdo.floatData();
        Serial.println(voltageS);
      // }
    } else {
      Serial.print("voltage error: ");
      Serial.println(fbdo.errorReason());
    }
    delay(5);
    if (Firebase.RTDB.getInt(&fbdo, "transmitter/mode")) {
      Serial.println(fbdo.dataType());
      // if (fbdo.dataType() == "int") {
        Serial.print("assigning mode: ");
        mode = uint8_t(fbdo.intData());
        Serial.println(mode);
      // }
    } else {
      Serial.print("mode error: ");
      Serial.println(fbdo.errorReason());
    }
  }
  delay(5);

  if (Firebase.RTDB.getFloat(&fbdo, "/setpoint")) {
    Serial.println(fbdo.dataType());
    // if (fbdo.dataType() == "float") {
      Serial.print("assigning setpoint: ");
      setpoint = fbdo.floatData();
      Serial.println(setpoint);
    // }
  } else {
    Serial.print("setpoint error: ");
    Serial.println(fbdo.errorReason());
  }
  delay(5);

  // if Vs > 3V then set mode to 2 (ACTIVE)
  if (mode == 1 && voltageS > 3.0) {
    mode = 2;
    // also update the firebase database that mode change has happened
    if (Firebase.RTDB.setInt(&fbdo, "transmitter/mode", mode)) {
      Serial.println("mode updated");
    } else {
      Serial.print("mode update error: ");
      Serial.println(fbdo.errorReason());
    }
    delay(5);
  }
  else if (mode == 2 && voltageS < 3.0) {
    mode = 1;
    // also update the firebase database that mode change has happened
    if (Firebase.RTDB.setInt(&fbdo, "transmitter/mode", mode)) {
      Serial.println("mode updated");
    } else {
      Serial.print("mode update error: ");
      Serial.println(fbdo.errorReason());
    }
    delay(5);
  }
}

void handler() {
  byte myArray[5];

  volt_i2c = uint16_t(voltageS * 100);
  setpoint_i2c = uint16_t(setpoint * 100);
 
  myArray[0] = (volt_i2c >> 8) & 0xFF;
  myArray[1] = volt_i2c & 0xFF;
  myArray[2] = (setpoint_i2c >> 8) & 0xFF;
  myArray[3] = setpoint_i2c & 0xFF;
  myArray[4] = mode;
  
  Serial.println("Sendingggg magic numbers");
  for (int i=0; i<5; i++) {
    Serial.println(myArray[i]);
  }
  Wire.write(myArray, 5);
}

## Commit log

2023-04-06 Make dashboard update powerState
2023-04-21 Add eFlexPWM and PID libraries
2023-05-02 Add code for secondary sensor reader
2023-05-02 Add READMe to secondary sensor reader
2023-05-04 Add Hardware folder
    [Drill_PTH_Through.DRL, Drill_PTH_Through_Via.DRL, Gerber_BoardOutlineLayer.GKO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]
2023-05-04 Add simulation and modelling directory
    [Wireless Power System Design.xlsx]
